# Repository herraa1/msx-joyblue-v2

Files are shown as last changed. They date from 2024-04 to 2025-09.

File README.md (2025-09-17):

# Bluetooth controller adapter for MSX (msx-joyblue) v2

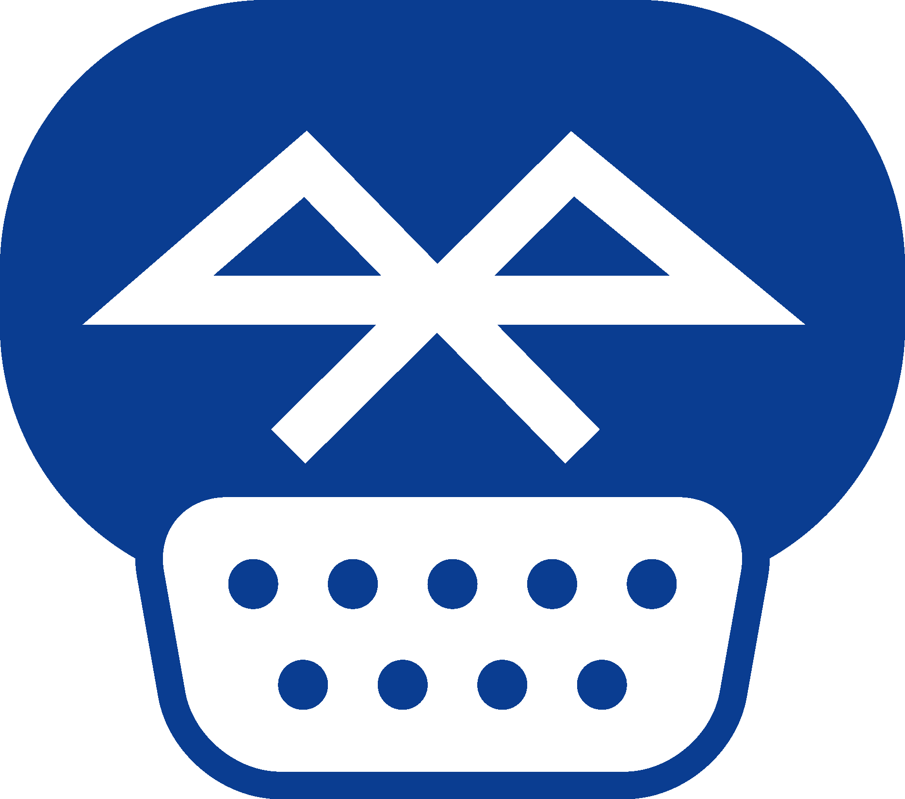
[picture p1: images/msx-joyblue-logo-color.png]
[](images/msx-joyblue-logo-color.png)

Connect Bluetooth controllers to [MSX computers](https://www.msx.org/wiki/)

## Introduction

The msx-joyblue is an adapter that allows connecting Bluetooth controllers to [MSX General Purpose I/O Interfaces](https://www.msx.org/wiki/General_Purpose_port) (aka joystick ports).

The adapter is based on the [unijoysticle2](https://github.com/ricardoquesada/unijoysticle2) and [bluepad32](https://github.com/ricardoquesada/bluepad32) projects, both owned by Ricardo Quesada.

The main features of the msx-joyblue v2 adapter are:
* small size
* made of widely available electronic components
* uses SMD components, so good soldering skills are needed to build the adapter
* emulates up to two MSX joysticks
* attaches to MSX computers using female standard DE9 connectors
* formally requires an external USB power supply as the adapter draws slightly more current than two MSX general purpose I/O interfaces can officially provide
* optionally, can be powered using MSX general purpose I/O interfaces without an external power supply if your MSX can safely supply enough current
* builtin leds provide information about the operation of the adapter

## [Hardware](hardware/kicad/)

The msx-joyblue v2 adapter uses an [ESP32-WROOM-32E chip](https://www.espressif.com/sites/default/files/documentation/esp32-wroom-32e_esp32-wroom-32ue_datasheet_en.pdf) to convert the Bluetooth controller actions to the [MSX joystick standard signalling](https://www.msx.org/wiki/Joystick_control).

A two-sided printed circuit board (PCB) is used to put together all components:
* The ESP32-WROOM-32E bluetooth MCU chip
* A CH340C USB to UART chip, to make it easy to upgrade firmware on the ESP32 chip
* A pair of S8050 NPN transistors to control the boot and enable signals of the ESP32 from the CH340C
* An AMS1117-3.3 regulator to convert the 5V from either the USB port or joystick ports to the 3.3V required by the ESP32 chip
* Four 74LS03 quad 2-input NAND gates with open collectors to completely mimic the standard MSX joystick behavior
* A pair of PTC fuses to minimize damage to the MSX computer in case something goes wrong with the board
* Several additional required components (diodes, leds, resistors, ceramic capacitors and an electrolytic capacitor)
* PH2.0 connectors are used to connect cable extensions
* A 2.0 pitch I2C header is added for future extensions
* Jumpers are provided to enable different power options
* A slider switch is used to enable powering the adapter from the MSX side
* Three momentary push buttons are used to reset the board, swap joysticks or change the operation mode

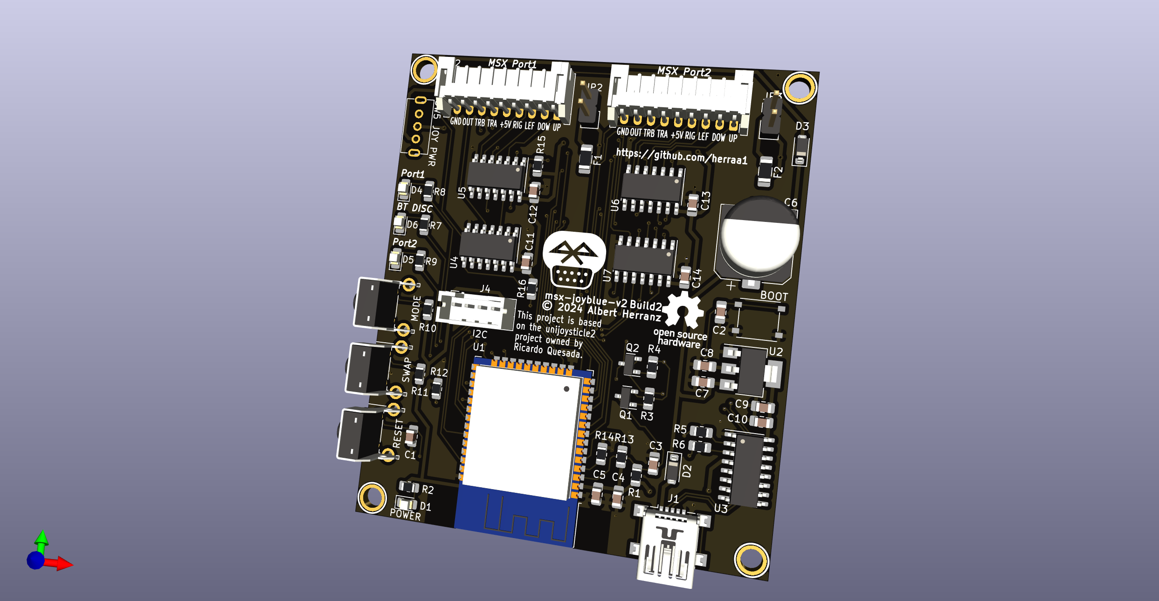
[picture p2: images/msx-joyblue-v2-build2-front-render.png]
[](images/msx-joyblue-v2-build2-front-render.png)

Connection to the MSX general purpose I/O interfaces is implemented using DE9 joystick extension cables with a female DE9 connector on one side and a loose end on the other side.
The MSX joystick extension cable loose end is wired according to the following pinout mapping.

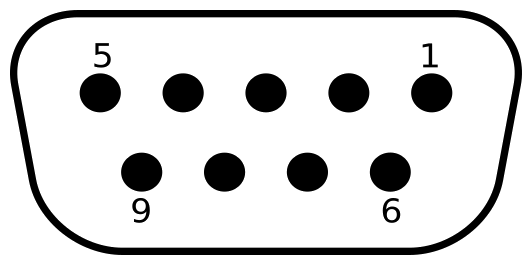
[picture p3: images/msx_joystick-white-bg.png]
| [](images/msx_joystick-white-bg.png) |
|:--|
| MSX joystick connector pinout, from controller plug side |

| MSX side pin | Cable color (may vary) | Signal |
| --- | --- | --- |
| 5 | Brown | +5v |
| 4 | Orange | RIGHT  |
| 3 | Grey | LEFT |
| 2 | Black | DOWN |
| 1 | Red | UP |
| 6 | Green | TRIG1  |
| 7 | White | TRIG2  |
| 8 | Blue | STROBE |
| 9 | Yellow | GND |

> [!WARNING]
> The msx-joyblue v2 adapter uses a different pin order on the PH2.0 header than the msx-joyblue v1 adapter.
>
> Make sure you respect the correct pin order for msx-joyblue-v2.
>

### Recommended Build

Please, use [msx-joyblue-v2 Build2c](#build2c) for making new boards.

You can find ready to order PCBs and the complete BoM at the [PCBWay community site](https://www.pcbway.com/project/shareproject/msx_joyblue_v2_build2c_caa88943.html).

<a href="https://www.pcbway.com/project/shareproject/msx_joyblue_v2_build2c_caa88943.html">PCB from PCBWay</a>

### [Build2c](hardware/kicad/msx-joyblue-v2-build2c)

[Interactive Bill Of Materials (BoM)](https://html-preview.github.io/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)

The Build2c adapter implements the following changes since Build2b:
* move capacitor C3 and resistor R1 closer to the ESP32 EN pin
* change C3 from 10uF to 22uF to give extra ramp up time to the 3V3 power rail

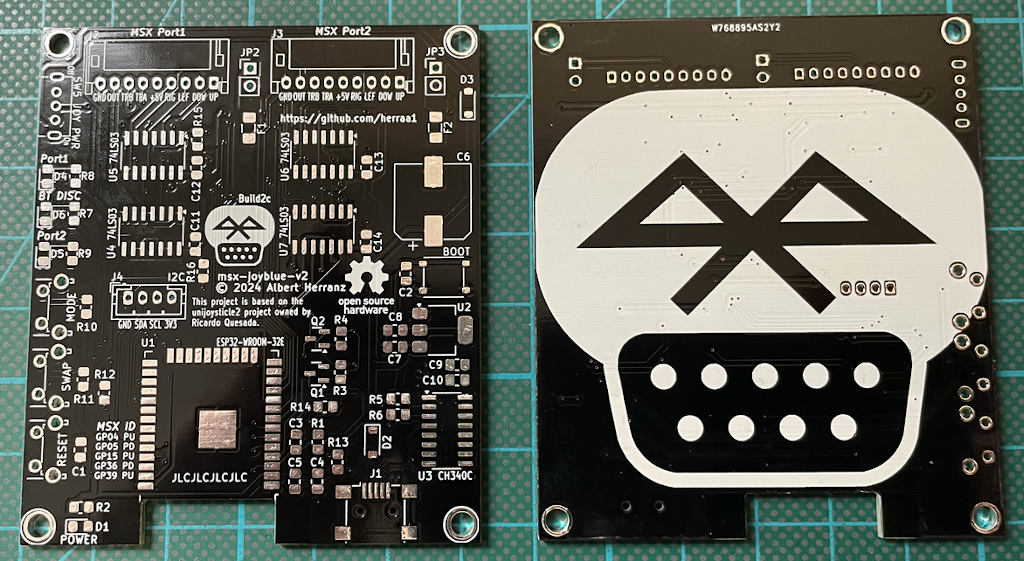
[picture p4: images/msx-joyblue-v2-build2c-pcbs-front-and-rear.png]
[](images/msx-joyblue-v2-build2c-pcbs-front-and-rear.png)|
|:--|
|msx-joyblue-v2 Build2c PCBs front and rear|

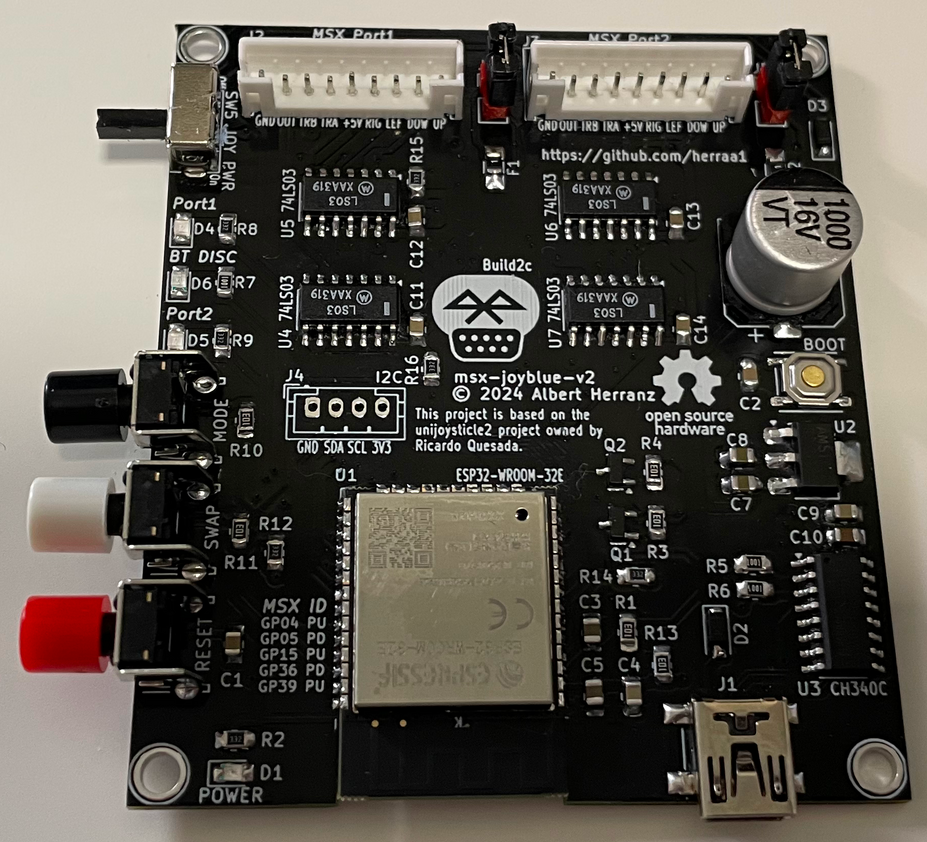
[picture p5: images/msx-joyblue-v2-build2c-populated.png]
|[](images/msx-joyblue-v2-build2c-populated.png)|
|:--|
|msx-joyblue-v2 Build2c populated PCB|

### Build2b

> [!NOTE]
> Build2b was never fabricated and has been marked obsolete. Use the [recommended build](#recommended-build) instead.

The Build2b is similar to Build2 but changes slightly some silkscreen text and graphics.

### Build2

> [!NOTE]
> Build2 has been marked obsolete. Use the [recommended build](#recommended-build) instead.

The Build2 adapter mimics completely the standard MSX joystick behavior:

* When pin8 is HIGH, the adapter puts all stick and triggers signals in high impedance mode irrespective of their status (as if stick and triggers were not hold in the standard MSX joystick schematic), which become HIGH on the MSX side via the MSX PSG related circuitry pull-ups (matching the expected behavior)
* When pin8 is LOW
  * if a stick direction or trigger is hold, the corresponding signal is pulled down to GND causing it to be LOW (matching the expected behavior)
  * if a stick direction or trigger is not hold, the corresponding signal is put in high impedance mode, which becomes HIGH on the MSX side via the MSX PSG related circuitry pull-ups (matching the expected behavior)

This build uses discrete logic components to honor the pin8 signaling (four [74LS03DR quad 2-input positive-nand gates with open collector outputs](https://www.ti.com/lit/ds/symlink/sn74ls03.pdf)) and uses open collector outputs which makes the adapter safer [^3] than the standard MSX joystick schematic depicted in the MSX Technical Data Book, as it avoids a series of undesired conditions that can lead to bus contention/short circuits.

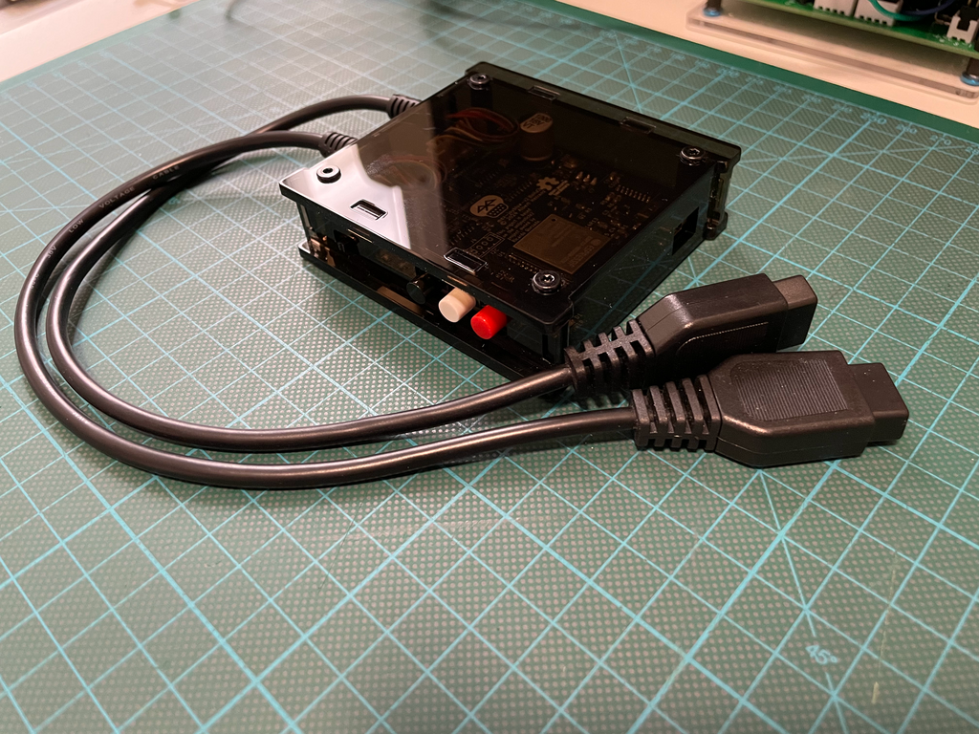
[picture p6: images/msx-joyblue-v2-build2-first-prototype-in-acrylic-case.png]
|[](images/msx-joyblue-v2-build2-first-prototype-without-enclosure.png)|[](images/msx-joyblue-v2-build2-first-prototype-in-acrylic-case.png)|
|-|-|
|msx-joyblue-v2 Build2 first prototype|msx-joyblue-v2 Build2 first prototype within acrylic case|

## [Firmware](https://github.com/ricardoquesada/bluepad32/tree/main)

The msx-joyblue v2 adapter firmware uses Ricardo Quesada [bluepad32](https://github.com/ricardoquesada/bluepad32/tree/main) library to drive Bluetooth controllers.
A [small modification](https://github.com/ricardoquesada/bluepad32/commit/9736bd169bc13ec625d469b8305d2ed2f46d6e69) to the library that enables support for MSX computers has been already commited to the _main_ branch.

See [bluepad32 documentation](https://github.com/ricardoquesada/bluepad32/tree/main/docs) for [supported Bluetooth controllers](https://github.com/ricardoquesada/bluepad32/blob/main/docs/supported_gamepads.md).

## [Enclosure](enclosure/)

A simple yet functional acrylic enclosure design is included.

## Powering the msx-joyblue adapter

The msx-joyblue adapter uses about ~107mA when operating, while a single MSX general purpose I/O interface is capable of delivering up to 50mA according to the MSX standard [^1].
That means that even using two MSX general purpose I/O interfaces (50mA + 50mA = 100mA) we are slightly over (107mA) the max current specification for the MSX general purpose I/O interfaces.

Thus, the safest way to power the msx-joyblue adapter is by powering it via the USB mini connector of the board using an external 5V USB power supply. The board automatically powers up when using the USB mini connector without enabling any switch.

Nevertheless, even if the MSX especification puts such a low limit on the current that can be drawn from a general purpose I/O interface, real MSX hardware usually can safely deliver enough current for the msx-joyblue adapter to work correctly without harming our beloved classic computers.

Taking that into account, the msx-joyblue adapter has been enabled to be optionally powered by the MSX general purpose I/O interfaces port 1 and port 2.

To enable powering the msx-joyblue adapter from _Port 1_ and/or _Port 2_, the switch SW5 _JOY PWR_ must be first turned on by sliding the switch handle to the right.

> [!NOTE]
> A [1N5819 SMD Schottky diode](https://www.diodes.com/assets/Datasheets/1N5819HW.pdf) D3 is used to avoid leaking current from the msx-joyblue adapter to the MSX in case the msx-joyblue adapter is powered by USB while the _JOY PWR_ switch is ON.
> Another [1N5819 SMD Schottky diode](https://www.diodes.com/assets/Datasheets/1N5819HW.pdf) D2 prevents backpowering the USB side from the MSX side.
> And two Positive Temperature Coeficient (PTC) resettable fuses F1 and F2 of 50mA each protect the MSX general purpose I/O interfaces port 1 and port 2 from excess of current in case something goes horribly wrong on the msx-joyblue adapter side.

To power the msx-joyblue adapter using the MSX general purpose I/O interfaces we must first understand how the PTC protections on the msx-joyblue adapter are implemented.

The selected PTCs are rated for 50mA which is the so called Hold Current (the maximum current that can flow in normal operation). There is also the Trip Current (the minimum current necessary for the PTC to move to high-resistance state) which for the selected PTCs is around 100mA. Those thresholds are dependent on temperature and voltage. And to make things more undeterministic, the behavior of the PTC when current is between those thresholds is undefined (it may trip or not).

In normal operation and for a room temperature of around 25 degrees Celsius, the selected PTCs in practice never trip below 75mA.

> [!NOTE]
> Depending on the exact PTCs installed, the trip current may be slightly different and the adapter may trip at a different point. Unless you buy the PTCs from a reliable source, it is very difficult to know the exact PTC specifications. 
>
> Remember that the PTCs are provided as a safeguard in case something goes really wrong on the adapter, not to act as an exact current limiter to strictly comply with the 50mA per-port MSX specification.

So **if our MSX computer can safely provide more than 50mA on each MSX general purpose I/O interface** (which is usually the case), we can connect both _Port 1_ and _Port 2_ to the MSX computer and turn on the SW5 _JOY PWR_ switch to power the msx-joyblue adapter. Note that we need to connect both ports even if we use just one Bluetooth gamepad, just to meet the power requirements.

Two jumpers JP2 and JP3 can be used to bypass the PTC protections for _Port 1_ and _Port 2_ respectively.

> [!WARNING]
> Bypassing the PTC protections may damage your MSX computer.
> Do not bypass the PTC protections unless you known what you are doing.

By closing JP2 (and/or JP3) and **if our MSX computer can safely provide more than 100mA on a single MSX general purpose I/O interface**, we can connect _Port 1_ (or _Port 2_) to the MSX computer and turn on the SW5 _JOY PWR_ switch to power the msx-joyblue adapter using a single joystick port.

In summary, we can use the following options to power the msx-joyblue adapter (from safest to less safe):
* via the board USB mini conector
  * leave open jumpers JP2 and JP3
  * turn off the SW5 _JOY PWR_ switch
  * connect a 5V USB power supply to the board USB mini connector
* via two MSX general purpose I/O interfaces, if your MSX can safely provide slightly more than 50mA on each MSX general purpose I/O interface
  * leave open jumpers JP2 and JP3
  * turn on the SW5 _JOY PWR_ switch
  * connect both _Port 1_ and _Port 2_ to the MSX general purpose I/O interfaces
* via one MSX general purpose I/O interface, if your MSX can safely provide more than 100mA on each MSX general purpose I/O interface
  * close jumpers JP2 and/or JP3
  * turn on the SW5 _JOY PWR_ switch
  * connect _Port 1_ or _Port 2_ to a MSX general purpose I/O interface

## Switches and Buttons

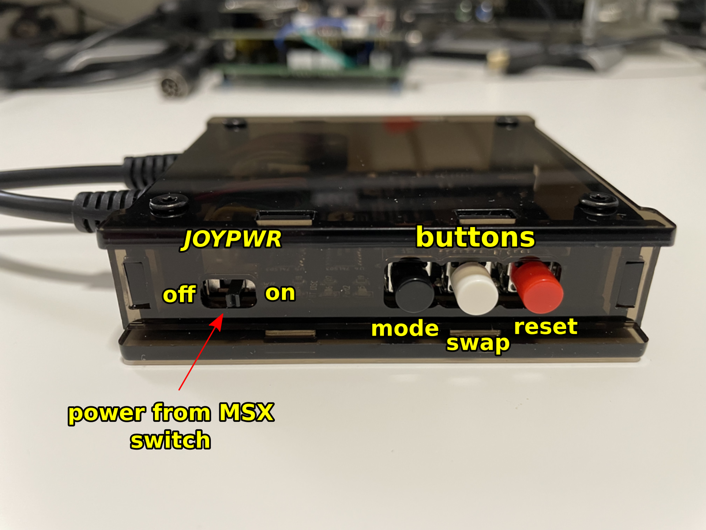
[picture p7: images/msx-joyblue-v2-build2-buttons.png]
[](images/msx-joyblue-v2-build2-buttons.png)

| **Switch** | **State** | **Description** |
|---|---|---|
| _JOYPWR_ | Off | power from MSX computer via joystick port(s) is off (except logic gates) |
| _JOYPWR_ | On | board electronics get power from MSX computer via joystick port(s) |

> [!NOTE]
> If you plug a +5V USB power supply to the USB mini connector, the adapter will turn on unconditionally irrespective of the _JOYPWR_ switch position.
>

| **Button** | **Description** |
|---|---|
| MODE | change the [operation mode](https://github.com/ricardoquesada/unijoysticle2/blob/main/docs/user_guide.md#unijoysticle-buttons-and-leds) of the connected gamepad between "basic mode" and "twin stick mode" |
| SWAP | swap connected gamepads between MSX joystick ports |
| RESET | restart the firmware, gamepads get disconnected |

## LED indicators

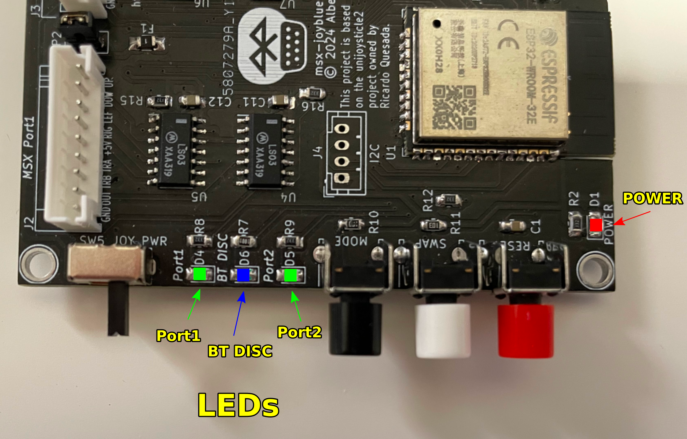
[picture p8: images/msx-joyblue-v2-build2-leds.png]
[](images/msx-joyblue-v2-build2-leds.png)

| **LED** | **State** | **Indication** |
|---|---|---|
| _POWER_ | Off | board is not receiving 3V3 power |
| _POWER_ | Solid Red | board is receiving 3V3 power |
| _Port1_ | Off | no gamepad is controlling _Port 1_ |
| _Port1_ | Solid Green | a connected gamepad is controlling _Port 1_ |
| _Port1_ | Blinking Green | Every 1sec, PTCs are tripping, see [Troubleshooting](#troubleshooting) |
| _Port2_ | Off | no gamepad is controlling _Port 2_ |
| _Port2_ | Solid Green | a connected gamepad is controlling _Port 2_ |
| _BT DISC_ | Off | Bluetooth discovery is off, no new connections are accepted, existing connections (if any) stay on |
| _BT DISC_ | Solid Blue | Bluetooth discovery is on, new connections are accepted, both "connects" and "re-connects" are accepted |

See also the [Unijoysticle user guide](https://github.com/ricardoquesada/unijoysticle2/blob/main/docs/user_guide.md#unijoysticle-buttons-and-leds), keeping in mind that led colors are slightly different.

## Troubleshooting

**Q: Just after powering the board _POWER_ led is solid red, _Port2_ and _BT DISC_ leds are off and the _Port1_ led is solid green, but the adapter does not work**

**A:** Press the reset button to reinitialize the adapter, the _BT DISC_ led should go solid blue shortly, when the adapter is ready.

**Q: I did the reset, but now the _Port1_ led blinks every second, the _BT DISC_ led is off and the _Port2_ is solid green but the adapter does not work**

**A:** The PTC fuses are tripping preventing the adapter to properly work. See the [Powering the msx-joyblue adapter](#powering-the-msx-joyblue-adapter) section: use a USB power supply or install the fuse bypass jumpers.

**Q: The _BT DISC_ led went off, what happened?**

**A:** You either have 2 gamepads already connected or have turned on the [_Twin Stick_ mode](https://github.com/ricardoquesada/unijoysticle2/blob/main/docs/user_guide.md#twin-stick-mode-aka-enhanced-mode).

This can happen too if the PTC fuses are tripping (see previous question).

**Q: My Wiimote does not connect**

**A:** If the adapter was previously connected, try pushing any Wiimote button until the Wiimote connects. If that does not work, open the battery compartment and press the red _SYNC_ button to pair the Wiimote with the adapter.

## Compatibility Tests

| **Model** | **Adapter PCB v2 Build2c** |
|---|---|
| [Sony MSX HB-101P](https://www.msx.org/wiki/Sony_HB-101P) | OK |
| [Sony MSX HB-501F](https://www.msx.org/wiki/Sony_HB-501F) | OK |
| [Toshiba MSX HX-10P](https://www.msx.org/wiki/Toshiba_HX-10P) | OK |
| [Philips MSX2 VG-8235](https://www.msx.org/wiki/Philips_VG-8235) | OK |
| [Panasonic MSX2+ FS-A1WSX](https://www.msx.org/wiki/Panasonic_FS-A1WSX) | OK |
| [Omega MSX2+](https://github.com/skiselev/omega) | OK |
| [MSXVR](https://msxvr.com/en/) | OK |
| [Tides Rider](https://genami.shop/products/tides-rider-hdk) | OK |
| [JFF-TMSHAT](https://github.com/herraa1/JFF-TMSHAT) | OK |

## Build Instructions

Follow these [Build instructions](Build.md) in order to assemble the msx-joyblue v2 adapter.

## References

Ricardo Quesada bluepad32 library
* https://github.com/ricardoquesada/bluepad32

Ricardo Quesada Unijoysticle2 project
* https://github.com/ricardoquesada/unijoysticle2

MSX general purpose I/O interface
* https://www.msx.org/wiki/General_Purpose_port

[^1]: https://www.msx.org/wiki/General_Purpose_port
[^2]: https://www.msx.org/wiki/MSX-HID
[^3]: https://www.msx.org/wiki/Joystick/joypad_controller (see "Undesired Conditions")

## Image Sources

* https://www.oshwa.org/open-source-hardware-logo/
* https://en.wikipedia.org/wiki/File:Numbered_DE9_Diagram.svg
* https://commons.wikimedia.org/wiki/File:Bluetooth.svg

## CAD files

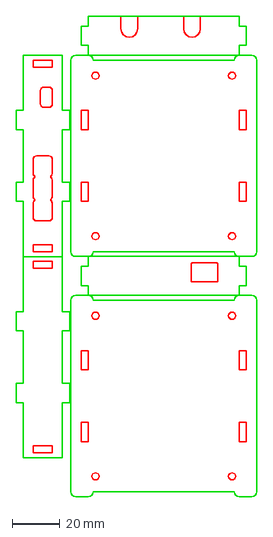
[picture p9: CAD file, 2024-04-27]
enclosure/msx-joyblue-v2-case-acrylic-3mm-ready-to-lasercut.dxf
100.4 x 200.5 mm

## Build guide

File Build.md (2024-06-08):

# Build Instructions

This document describes how to assemble the msx-joyblue v2 adapter.

# Assembling the msx-joyblue v2 adapter

## Bill Of Materials

| **ref** | **component** | **req_pcs** | **item_description** | **item_option** | **pcs_per_item** | **req_items** | **link** |
| --- | --- | --- | --- | --- | --- | --- | --- |
| C1,C2,C4,C9,C11,C12,C13,C14 | 0805 0.1uF capacitor | 8 | 100pcs 0805 SMD Chip Multilayer Ceramic Capacitor 0.5pF - 47uF 10pF 22pF 100pF 1nF 10nF 100nF 0.1uF 1uF 2.2uF 4.7uF 10uF 22uF | 100nF | 100 | 1 | [aliexpress](https://www.aliexpress.com/item/1005005690917856.html) |
| C3,C5,C7,C8 | 0805 22uF capacitor | 4 | 100pcs 0805 SMD Chip Multilayer Ceramic Capacitor 0.5pF - 47uF 10pF 22pF 100pF 1nF 10nF 100nF 0.1uF 1uF 2.2uF 4.7uF 10uF 22uF | 22UF | 100 | 1 | [aliexpress](https://www.aliexpress.com/item/1005005690917856.html) |
| C6 | 10x10.5 2200uF aluminum capacitor | 1 | 10PCS 10X10.5 chip aluminum electrolytic capacitor 10V 16V 25V 35V 50V 63V 100V 100UF 220UF 330UF 470UF 680UF 1000UF | 16V1000UF | 10 | 1 | [aliexpress](https://www.aliexpress.com/item/1005005475565293.html) |
| C10 | 0805 1uF capacitor | 1 | 100pcs 0805 SMD Chip Multilayer Ceramic Capacitor 0.5pF - 47uF 10pF 22pF 100pF 1nF 10nF 100nF 0.1uF 1uF 2.2uF 4.7uF 10uF 22uF | 1UF | 100 | 1 | [aliexpress](https://www.aliexpress.com/item/1005005690917856.html) |
| R2,R8,R9,R12,R14,R15,R16 | 0805 3.3K resistor | 7 | 200PCS 660PCS 720PCS 4000PCS 0402 0603 0805 1206 1210 2512 SMD Resistor Kit igmopnrq Assorted Kit 10K 100K 1K 1R 100R 220R 1% 5% | 0805 720PCS 36Values | 20 | 1 | [aliexpress](https://es.aliexpress.com/item/1005005671741256.html) |
| R1,R3,R4,R10,R11,R13 | 0805 10K resistor | 6 | 200PCS 660PCS 720PCS 4000PCS 0402 0603 0805 1206 1210 2512 SMD Resistor Kit igmopnrq Assorted Kit 10K 100K 1K 1R 100R 220R 1% 5% | 0805 720PCS 36Values | 20 | 0 | [aliexpress](https://es.aliexpress.com/item/1005005671741256.html) |
| R5,R6,R7 | 0805 1K resistor | 3 | 200PCS 660PCS 720PCS 4000PCS 0402 0603 0805 1206 1210 2512 SMD Resistor Kit igmopnrq Assorted Kit 10K 100K 1K 1R 100R 220R 1% 5% | 0805 720PCS 36Values | 20 | 0 | [aliexpress](https://es.aliexpress.com/item/1005005671741256.html) |
| D2,D3 | SOD-123 1N5819 schottky diode | 2 | 100pcs SMD diode 0805 SOD-123 S4 1N5819 1N5819W 1N5819WS 1N5819WT SOD-323 SOD-523 1206 0603 Schottky diodes | SOD-123 | 100 | 1 | [aliexpress](https://www.aliexpress.com/item/1005006207828437.html) |
| D1 | 0805 Red Led | 1 | 100pcs=5colors x 20pcs 5050 5730 3014 1210 2835 3528 1206 0805 0603 0402 SMD LED Diode Kit Red / Green / Blue / White / Yellow | Emitting Color: 0805 5colors 20pcs | 20 | 1 | [aliexpress](https://www.aliexpress.com/item/4001031824623.html) |
| D4,D5 | 0805 Green Led | 2 | 100pcs=5colors x 20pcs 5050 5730 3014 1210 2835 3528 1206 0805 0603 0402 SMD LED Diode Kit Red / Green / Blue / White / Yellow | Emitting Color: 0805 5colors 20pcs | 20 | 0 | [aliexpress](https://www.aliexpress.com/item/4001031824623.html) |
| D6 | 0805 Blue Led | 1 | 100pcs=5colors x 20pcs 5050 5730 3014 1210 2835 3528 1206 0805 0603 0402 SMD LED Diode Kit Red / Green / Blue / White / Yellow | Emitting Color: 0805 5colors 20pcs | 20 | 0 | [aliexpress](https://www.aliexpress.com/item/4001031824623.html) |
| U4,U5,U6,U7 | 74LS03DR | 4 | 10pcs SN74LS00DR SN74LS02DR SN74LS04DR SN74LS05DR SN74LS08DR SN74LS14DR SN74LS32DR SN74LS03DR SN74LS05DR2 SN74LS06DR SOP-14 | SN74LS03DR | 10 | 1 | [aliexpress](https://www.aliexpress.com/item/1005006266817606.html) |
| U1 | ESP32-WROOM-32E | 1 | 1pcs ESP-WROOM-32/32D/32U/32E WiFi Bluetooth 4.2 dual-core CPU MCU low- Bluetooth 240MHZ ESP32 chip ESP-32S | ESP32-WROOM-32E | 1 | 1 | [aliexpress](https://www.aliexpress.com/item/1005006387597679.html) |
| U2 | AMS1117-3.3 | 1 | 50PCS AMS1117 series AMS1117-1.2 AMS1117-1.5 AMS1117-1.8 AMS1117-2.5 AMS1117-3.3 AMS1117-5.0 SOT223 new | AMS1117-3.3V | 50 | 1 | [aliexpress](https://www.aliexpress.com/item/1005006122970723.html) |
| U3 | CH340C | 1 | 10PCS Chipset CH340C CH340 SOP-16 | | 10 | 1 | [aliexpress](https://www.aliexpress.com/item/1005006121593217.html) |
| F1,F2 | 1206 50mA PTC fuse | 2 | 10PCS Self-Recoverable SMD Fuse PPTC 0805 0.05A 50MA 100MA 0.2A 0.35A 0.5A 750MA 1A 1.1A 1.25A 1.5A 2A 6V 9V 12V 16V 24V 30V 48V | 0805 50MA 24V | 10 | 1 | [aliexpress](https://www.aliexpress.com/item/1005005816556049.html) |
| SW1,SW3,SW4 | 6x6mm momentary switch right angle | 3 | 6x6mm Panel PCB Momentary Tactile Tact Mini Switch 6\*6\*4.3/5/6/7/89/10/12mm Right Angle With stent 6x6x4.3mm 5mm 6mm 7mm 8mm 9mm  | 6x6x9mm | 20 | 1 | [aliexpress](https://www.aliexpress.com/item/32912894177.html) |
| SW2 | 5.1x5.1 1pst push button | 1 | 10PCS 3\*6 3\*4 4\*4 SMD Tactile Tact Push Button Switch 2Pin 4Pin Touch Micro Switch 3x4x2 3x6x4.3 3x6x2.5 3x6x5 4x4x1.5 4\*4\*2.5 | 4X4X1.5MM | 10 | 1 | [aliexpress](https://www.aliexpress.com/item/1005004067514307.html) |
| SW5 | SK12D07G6 1P2T switch | 1 | 10PCS SK12D07G3/4/5/6/7MM Mini Vertical Slide Switch 1P2T 3 Pin Toggle Switch SMD PCB DPDT Vertical Switch High Quality | 6MM | 10 | 1 | [aliexpress](https://www.aliexpress.com/item/1005005897805728.html) |
| Q1,Q2 | SOT-23 S8050 transistor | 2 | SOT23 S9014 S9015 S8050 S8550 SS8050 SS8550 S9012 S9013 S9018 J3Y STY Y1 Y2 2T1 J3 J6 M6 J8 Transistor XC6206P332MR XC6206P182MR | 50PCS S8050 J3Y | 50 | 1 | [aliexpress](https://www.aliexpress.com/item/1005004417008064.html) |
| JP2,JP3 | 2.54mm pin header | 1 | 30PCS 40 Pin Breakable Pin Header 2.54mm Single Row Male Header Connector Kit PCB Pin Strip For Arduino | | 30 | 1 | [aliexpress](https://www.aliexpress.com/item/1005006186853439.html) |
| J1 | USB Mini B connector | 1 | 10PCS Mini USB SMD 5 Pin Female Mini B Socket Connector Plug Straight DIP Jack Connector Plug-in | Color: G | 10 | 1 | [aliexpress](https://www.aliexpress.com/item/1005004679855929.html) |
| J2,J3 | 9pin PH2.0 straight male connector | 2 | 20sets XH 2.54mm PH2.0 Straight Right angle 2/3/4/5/6/7/8/9/10/12/14/15/16/20 pin JST Connector XHP PHR 2.5 Male Female Terminal | Straight Type, PH2.0mm, 9P | 20 | 1 | [aliexpress](https://www.aliexpress.com/item/1005003475317382.html) |
| \- | PCB | 1 | msx-joyblue-v2 build2c pcb | | 5 | 1 | [PCBWay](https://www.pcbway.com/project/shareproject/msx_joyblue_v2_build2c_caa88943.html) |

## Tools

I used the following tools and materials to assemble the msx-joyblue v2 board:

* silicone heat-resistant mat (TE-616 400x290mm)
* electronic microscope with 2 LEDs (KKmoon 3" LCD 10X-300X 3.0MP 1080P HDMI electronic digital video microscope)
* soldering station (Yihua 908D)
* T1.C "horseshoe" soldering tip (900M series)
* flux (Mechanic UV80 flux paste)
* solder (0.5mm, for hobby projects you may use 60% Sn / 40% Pb Flux 2% at your own risk)
* desoldering wick (2.5mm is fine, for correcting mistakes if you are human)

## Testing the Integrated Circuits

It is highly recommended to test the integrated circuits before soldering them, specially if you buy chips from cheap Asian stores.
Otherwise, you'll need to desolder any non-working chip after soldering them on the PCB and realizing they really don't work.

### CH340C

The CH340C is a SOP-16 packaged USB to serial chip that requires few external components to function, thus it is very easy to build a test circuit.

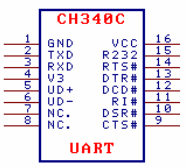
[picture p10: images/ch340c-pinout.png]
|[](images/ch340c-pinout.png)|
|:--|
|CH340C pinout|

In order to minimally test a CH340C chip we just need to connect GND, VCC, USBD+, USBD- and put a 100nF capacitor between V3 and GND, as indicated in the following diagram.

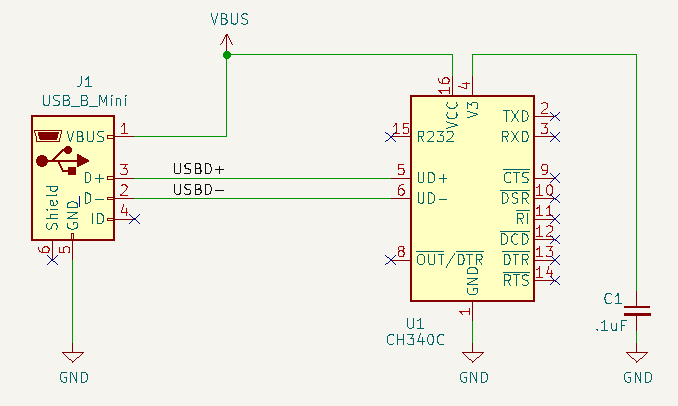
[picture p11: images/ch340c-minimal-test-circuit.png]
|[](images/ch340c-minimal-test-circuit.png)|
|:--|
|CH340C minimal test circuit|

This circuit can be easily built using the following components:
* [USB-A male to 2.54mm female dupont header cable](https://www.aliexpress.com/item/4000916333572.html)
* [SOP-16 to DIP-16 adapter](https://www.aliexpress.com/item/1005005939115495.html)
* [0.1uF ceramic capacitor](https://www.aliexpress.com/item/32973259342.html)
* [male-male jumper wires](https://www.aliexpress.com/item/1005006263457745.html)
* [breadboard](https://www.aliexpress.com/item/1005006102317693.html)

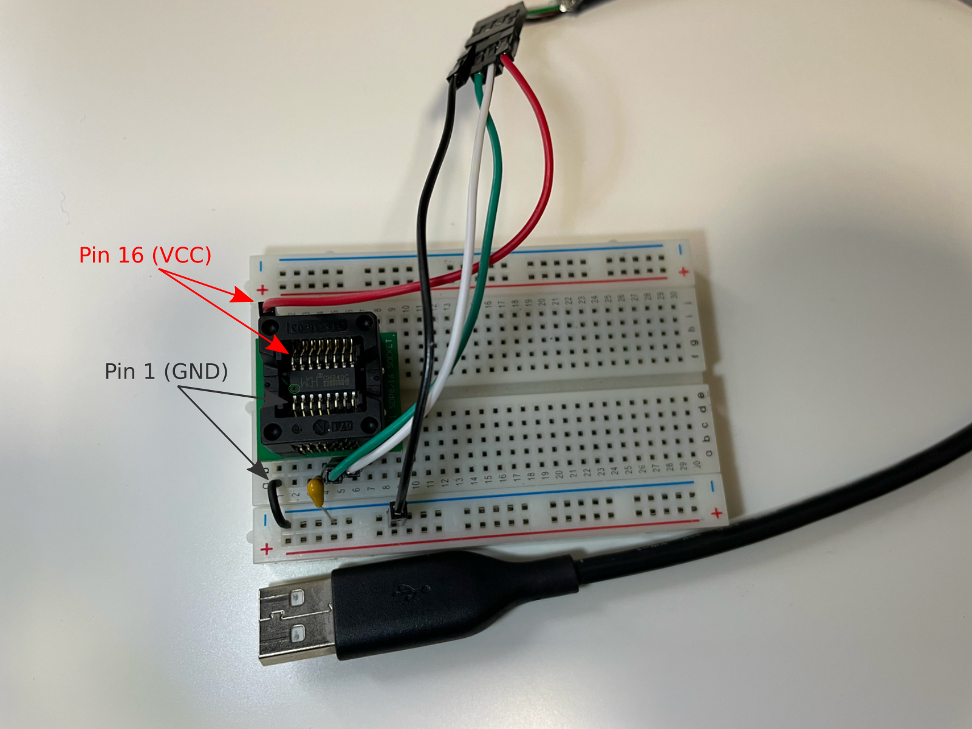
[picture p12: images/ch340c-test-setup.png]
|[](images/ch340c-test-setup.png)|
|:--|
|CH340C test setup|

When you have the test circuit ready, push down and hold the top of the SOP-16 to DIP-16 adapter to open the adapter pin "jaws", using precision tweezers insert and perfectly align the CH340C chip with the adapter pin "jaws" and finally release the top of the adapter to have the chip secured and correctly connected. You can now connect the USB-A cable to your computer and look for the CH340 device in the list of USB devices.

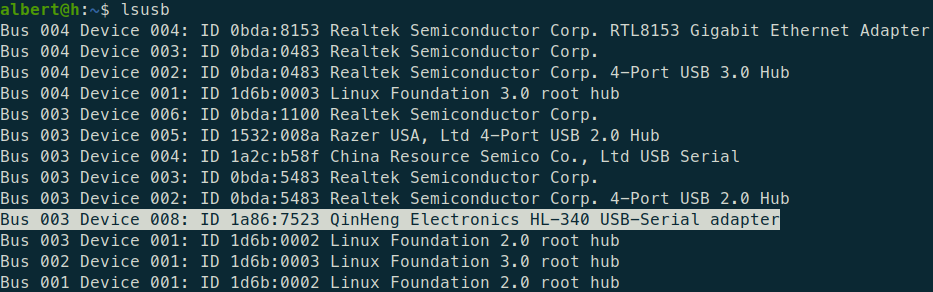
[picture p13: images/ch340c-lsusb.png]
|[](images/ch340c-lsusb.png)|
|:--|
|CH340C adapter correctly recognized|

To remove the chip from the SOP-16 to DIP-16 adapter you will need to push and hold again the top of the adapter, lift gently the chip using tweezers and then release the top of the adapter when it is empty.

### ESP32-WROOM-32E

The ESP32-WROOM-32E is a powerful Wi-Fi + Bluetooth + Bluetooth LE microcontroller unit module with an embedded PCB antenna.

Testing a ESP32-WROOM-32E can be achieved with a [small ready-to-use test jig](https://www.aliexpress.com/item/1005005850152605.html).

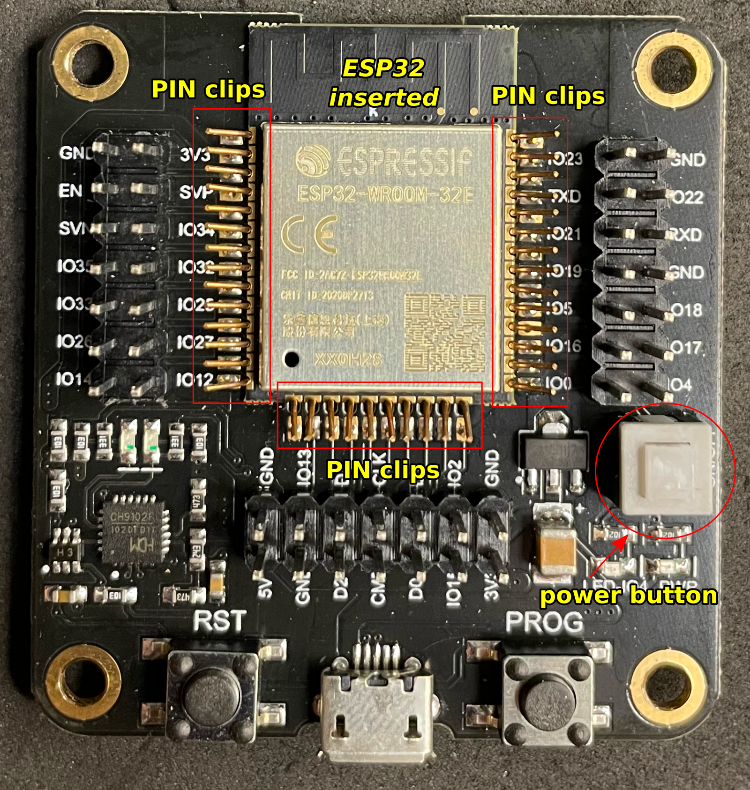
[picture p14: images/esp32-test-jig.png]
|[](images/esp32-test-jig.png)|
|:--|
|ESP32-WROOM-32E test jig|

To test a ESP32-WROOM-32E:
* Insert the ESP32-WROOM-32E into the test jig making sure that all pads are aligned with the test jig clips.

  You need to press firmly the module until it gets hold by the clips of the test jig, without breaking any clips.
* Insert a micro-USB cable into the micro-USB connector of the test jig and connect it to your PC
* Press the power button to turn on the test jig.
* Check that the USB to serial adapter shows up on the list of USB devices of your PC

<pre>
$ dmesg | tail -n 6
[  940.416575] usb 3-3.1: new full-speed USB device number <b>40</b> using xhci_hcd
[  940.517893] usb 3-3.1: New USB device found, idVendor=<b>1a86</b>, idProduct=<b>55d4</b>, bcdDevice= 4.44
[  940.517900] usb 3-3.1: New USB device strings: Mfr=0, Product=2, SerialNumber=3
[  940.517904] usb 3-3.1: Product: <b>USB Single Serial</b>
[  940.517908] usb 3-3.1: SerialNumber: XXXXXXXXXX
[  940.568222] cdc_acm 3-3.1:1.0: <b>ttyACM0: USB ACM device</b>
</pre>

<pre>
$ lsusb
Bus 004 Device 004: ID 0bda:8153 Realtek Semiconductor Corp. RTL8153 Gigabit Ethernet Adapter
Bus 004 Device 003: ID 0bda:0483 Realtek Semiconductor Corp. 4-Port USB 3.0 Hub
Bus 004 Device 002: ID 0bda:0483 Realtek Semiconductor Corp. 4-Port USB 3.0 Hub
Bus 004 Device 001: ID 1d6b:0003 Linux Foundation 3.0 root hub
Bus 003 Device 006: ID 0bda:1100 Realtek Semiconductor Corp. USB2.0 HID
Bus 003 Device 005: ID 1532:008a Razer USA, Ltd RZ01-0325, Gaming Mouse [Viper Mini]
Bus 003 Device 004: ID 1a2c:b58f China Resource Semico Co., Ltd BladeMaster TE 88K
Bus 003 Device 003: ID 0bda:5483 Realtek Semiconductor Corp. 4-Port USB 2.0 Hub
Bus 003 Device 002: ID 0bda:5483 Realtek Semiconductor Corp. 4-Port USB 2.0 Hub
<b>Bus 003 Device 040: ID 1a86:55d4 QinHeng Electronics USB Single Serial</b>
Bus 003 Device 024: ID 050d:0304 Belkin Components FSU304 USB 2.0 - 4 Ports Hub
Bus 003 Device 001: ID 1d6b:0002 Linux Foundation 2.0 root hub
Bus 002 Device 001: ID 1d6b:0003 Linux Foundation 3.0 root hub
Bus 001 Device 001: ID 1d6b:0002 Linux Foundation 2.0 root hub
</pre>

* Then finally use esptool to request information about the chip.

  If the chip works fine it will be properly detected and will appear as ESP32-D0WD-V3 or ESP32-D0WDR2-V3.

<pre>
$ <b>esptool.py chip_id</b>
esptool.py v3.3.4-dev
Found 1 serial ports
Serial port /dev/ttyACM0
Connecting....
Detecting chip type... Unsupported detection protocol, switching and trying again...
Connecting.......
Detecting chip type... ESP32
<b>Chip is ESP32-D0WD-V3 (revision v3.1)</b>
Features: WiFi, BT, Dual Core, 240MHz, VRef calibration in efuse, Coding Scheme None
Crystal is 40MHz
MAC: 01:23:45:67:89:ab
Uploading stub...
Running stub...
Stub running...
Warning: ESP32 has no Chip ID. Reading MAC instead.
MAC: 01:23:45:67:89:ab
Hard resetting via RTS pin...
</pre>

### SN74LS03DR

The SN74LS03DR are quad 2-input NAND gates with open collector outputs.

If you own a TL866II+ programmer you can easily verify that the 74LS03 chips are working correctly.

Use the same SOP-16 to DIP-16 adapter that you used to test the CH340C, but keep in mind that the SN74LS03DR only has 14 pins so you need to properly align the IC leaving 2 pairs of pins unconnected.

Insert the DIP-16 adapter into the TL866II+ connector making sure that pin 1 is aligned correctly (use the engraved orientation diagram as a reference).

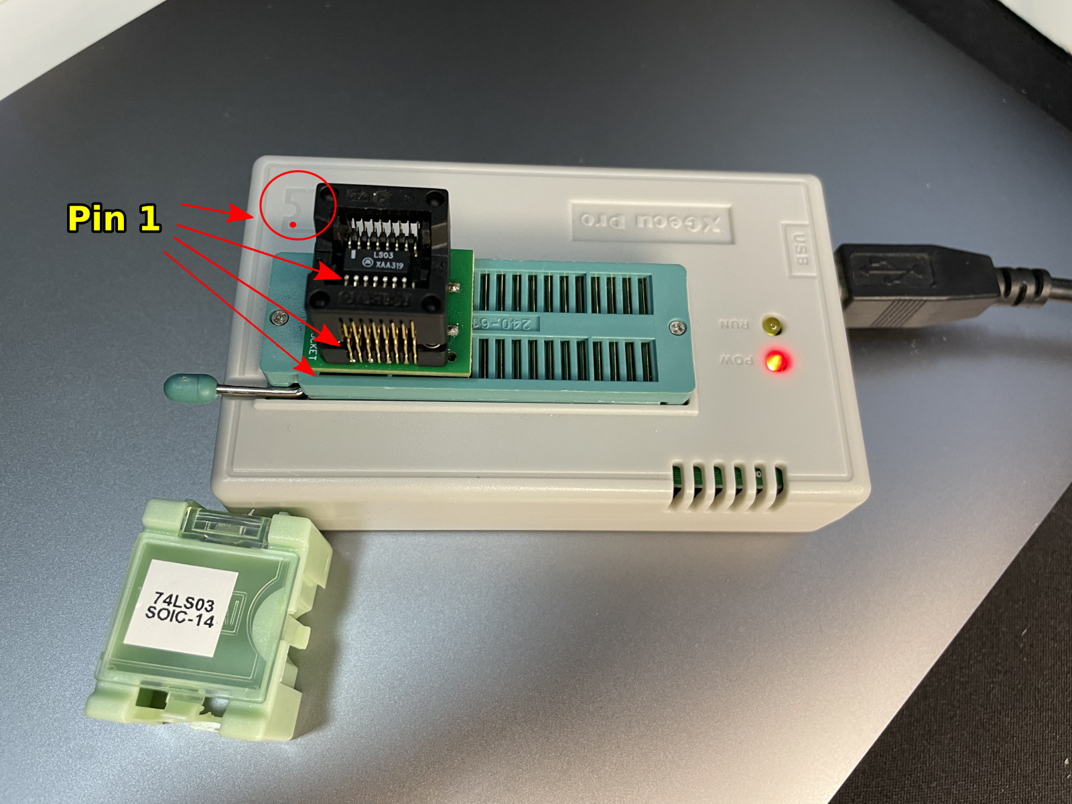
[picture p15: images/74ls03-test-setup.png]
|[](images/74ls03-test-setup.png)|
|:--|
|SN74LS03DR test setup|

Then use the minipro software to test the logic gates.

<pre>
$ <b>./minipro -p 7403 -T</b>
Found TL866II+ 04.2.132 (0x284)
      1  2  3  4  5  6  7  8  9  10 11 12 13 14
0000: 0  0  Z  0  0  Z  G  Z  0  0  Z  0  0  V
0001: 1  0  Z  1  0  Z  G  Z  1  0  Z  1  0  V
0002: 0  1  Z  0  1  Z  G  Z  0  1  Z  0  1  V
0003: 1  1  L  1  1  L  G  L  1  1  L  1  1  V
<b>Logic test successful.</b>
</pre>

## Board assembly instructions

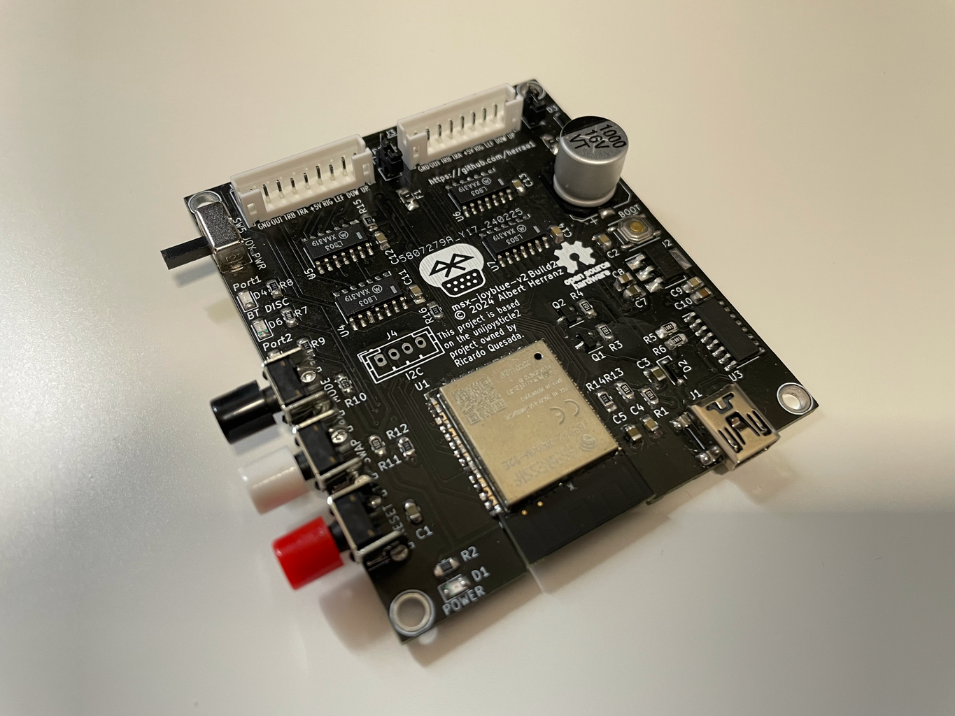
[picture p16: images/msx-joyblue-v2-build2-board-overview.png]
[](images/msx-joyblue-v2-build2-board-overview.png)

### Component orientation

#### Polarized components

As always, make sure to align all the polarized components correctly:
* the aluminum capacitor has a black color zone at the top indicating the negative pad, and also the base is beveled on the positive pad which must match the footprint at the PCB
* the leds have color markings near the negative pad
* the 1N5819 schottky diodes have a strip on the negative pad
* the CH340C USB to serial chip has a dot marking near pin 1

  Pin 1 of CH340C must be aligned to the PCB footprint (depending on the footprint used) with the pin marked with a small arrow or the pin where the silkscreen line extends to the end of the pin
* the SN74LS03DR chips have a vertical line close to the side where pin 1 is, but it does NOT indicate which pin is pin 1 (pin1 is on the bottom left when you orient the chip so that the markings can be read correctly)

  Pin1 of SN74LS03DR must be aligned to the PCB footprint in the same way as described for the CH340C chip.

* PH2.0 headers must be oriented according to the PCB footprint silkscreen drawing

* The rest of polarized components (3V3 regulator, transistors, momentary mini buttons, tactile push button, sliding switch and USB mini connector) can only be installed in the correct orientation

|[](images/msx-joyblue-v2-build2-polarized-components-orientation.png)|
|:--|
|Polarized components orientation|

#### Non-polarized components

All ceramic capacitors, resistors, fuses and pin headers are non-polarized and can be installed in any orientation.

### Soldering

You can use many different strategies and techniques to solder the components into the PCB.

You can have a look at one of the many tutorials available on youtube:

(https://www.youtube.com/watch?v=EW9Y8rDm4kE)
(https://www.youtube.com/watch?v=zS0w5-6keVU)
(https://www.youtube.com/watch?v=4SzV2_ZmRK0)

I use this technique for SMD components:
* Put flux paste/gel into the PCB pads of the footprint of the component that you want to solder.
* Place and align the component on top of its PCB footprint. The component will stick to the PCB thanks to the flux paste/gel.

  It is advisable to use precision tweezers and a microscope to make the component alignment, unless you have very good eyesight.

* Put a really small quantity of solder into the base of the T1.C tip of the soldering iron, which should be already at 350 degrees Celsius. The flux of the solder will evaporate while at the tip, but that's no problem as we will use the flux from the PCB pads.
* Hold the component with tweezers so that it does not move while soldering the first of its pads.
* Put the tip of the soldering iron with the solder so that it touches both the PCB pad and component leg. The solder at the soldering iron tip will mix with the flux at the PCB pad creating a good solder joint.

  You can move the soldering iron tip into and out of the component leg to make sure the solder makes a good metal junction.

* Repeat the process with the remaining pads. If the component has many pads, solder first two pads in opposite diagonals to secure the component, then go after the rest of the pads.
* Clean the excess of flux using pure isopropyl alcohol.

I would suggest to solder the components in decreasing difficulty order, making batches of identical valued components to avoid mistakes, also leaving for the end the taller SMD components (like the aluminum capacitor and the USB mini connector) and the through-hole components (like the PH2.0 headers, right-angled buttons and sliding switch), but do as you feel comfortable.

>[!NOTE]
> You are not required to solder the ESP32 ground pad at the bottom of the chip (this is specially relevant if you use a soldering iron to solder it).

>[!NOTE]
> After soldering it is strongly advisable to verify the continuity of all signals using a digital multimeter, with special emphasis on the ESP32 chip pins (which may not provide good contact with the pads, despite looking properly soldered).

[](images/msx-joyblue-v2-build2-pcb-assembly.gif)

# Preparing the joystick cables

## Bill Of Materials

| **ref** | **component** | **req_pcs** | **item_description** | **item_option** | **pcs_per_item** | **req_items** | **link** |
| --- | --- | --- | --- | --- | --- | --- | --- |
| \- | 9pin PH2.0 straight female socket | 2  | 10PCS JST Plugs Sockets XH2.54/PH2.0/SH1.0/ZH1.5/JST1.25 Connectors 10/9/8/7/6/5/4/3/2 Pin connector Case Without Wire Connector | Color: Housing Case, Package: PH 2.0mm, Pins: 9P | 10  | 1 | [aliexpress](https://www.aliexpress.com/item/1005006058022917.html) |
| \- | PH2.0 pin terminals | 18 | 500Pcs JST PH 2.0 2.0mm Metal Pins Terminal Wire Cable for Housing PH2.0 Female Socket Connector | | 500 | 1 | [aliexpress](https://www.aliexpress.com/item/1005006603250204.html) |
| \- | Cable gland 5mm | 2  | 10pcs Cable Gland Connector Rubber Strain Relief Cord Boot Protector Wire Cable Sleeve Power Tool Cellphone Charger | 5mm-black, China | 10  | 1 | [aliexpress](https://www.aliexpress.com/item/1005005914224947.html) |
| \- | Extension cable MSX | 2  | 1PC 9 Pin 1.5M Extension Cable For Sega Genesis 2 for MD2 Controller Gamepad | Color: as pic | 1 | 2 | [aliexpress](https://www.aliexpress.com/item/1005005677059954.html) |

## Tools

I used the following tools to prepare the DE9 cables:

* wire stripper & cutter (Stanley FatMax)
* PH2.0 crimping tool (SN-01BM)

## Cable assembly instructions

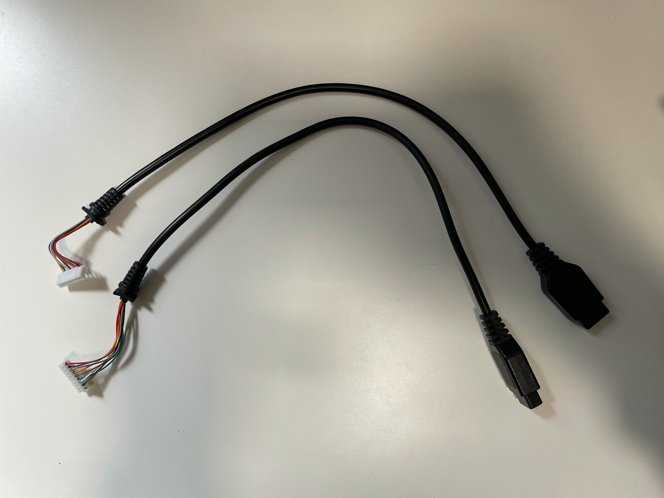
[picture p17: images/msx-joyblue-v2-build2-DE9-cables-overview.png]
[](images/msx-joyblue-v2-build2-DE9-cables-overview.png)

Although you can use the DE9 extension cables as is, they are quite long (1.5m) for the msx-joyblue adapter: it is recommended to adjust them to about 35cm long, which requires cutting the cable, stripping again the 9 internal wires and placing a new cable gland for strain relief.

You need to crimp PH2.0 metal pins to all of the joystick cable wires. Make sure that you crimp the sleeve of the wire with the rear wings of the PH2.0 metal pin only, and that the center wings crimp the stripped copper wire. If the wire is too thin to get properly crimped, you can fold a bit the stripped copper wire at the end of the wire so that the central wings have more copper volume to crimp.

Once the PH2.0 metal pins are correctly crimped you can insert them into the PH2.0 plastic housing in the specific required order.

This is the detailed procedure to prepare each of the two DE9 cable extensions:

1. Cut the DE9 extension cable leaving about 35cm from the DE9 connector.

   TBC

2. Use the wire stripper to remove about 5cm of the cable insulation at the cut end, exposing the 9 internal wires.

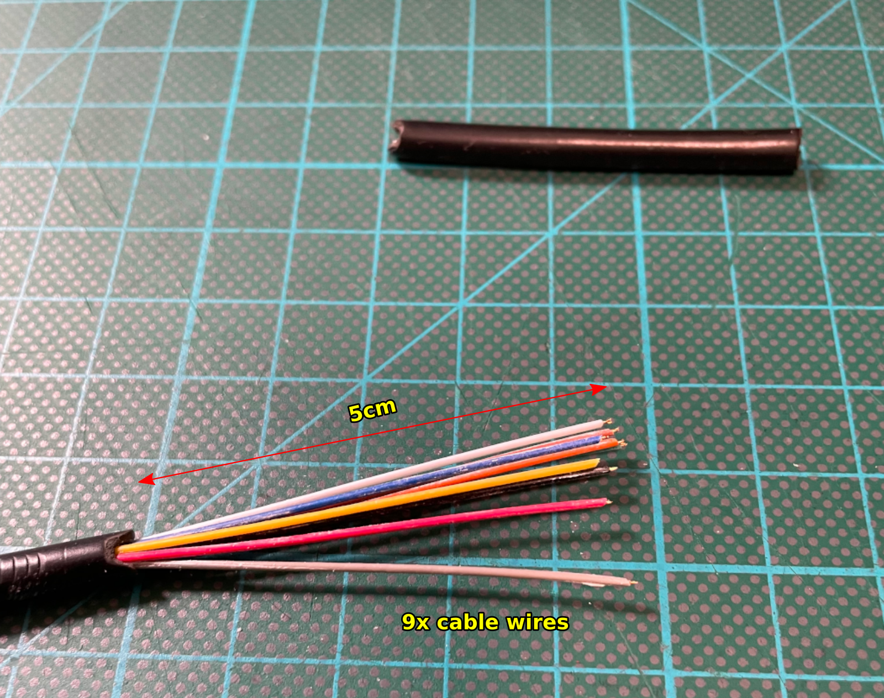
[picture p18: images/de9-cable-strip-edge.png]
[](de9-cable-strip-edge.png)

3. Insert the cable gland at the cut end of the extension cable.

   You must first insert the cable gland via its "conic" side into the 9 internal wires. From there you need to keep sliding the cable gland into the cable until the cable gland is fully inserted into the external cable insulation.
   
   You may need to use a bit of dish soap to fit the cable gland into the cable, as it fits very tight.

   TBC

4. For each one of the 9 internal wires:

   4.1. Use the wire stripper to remove about 2-3mm of the individual cable insulation

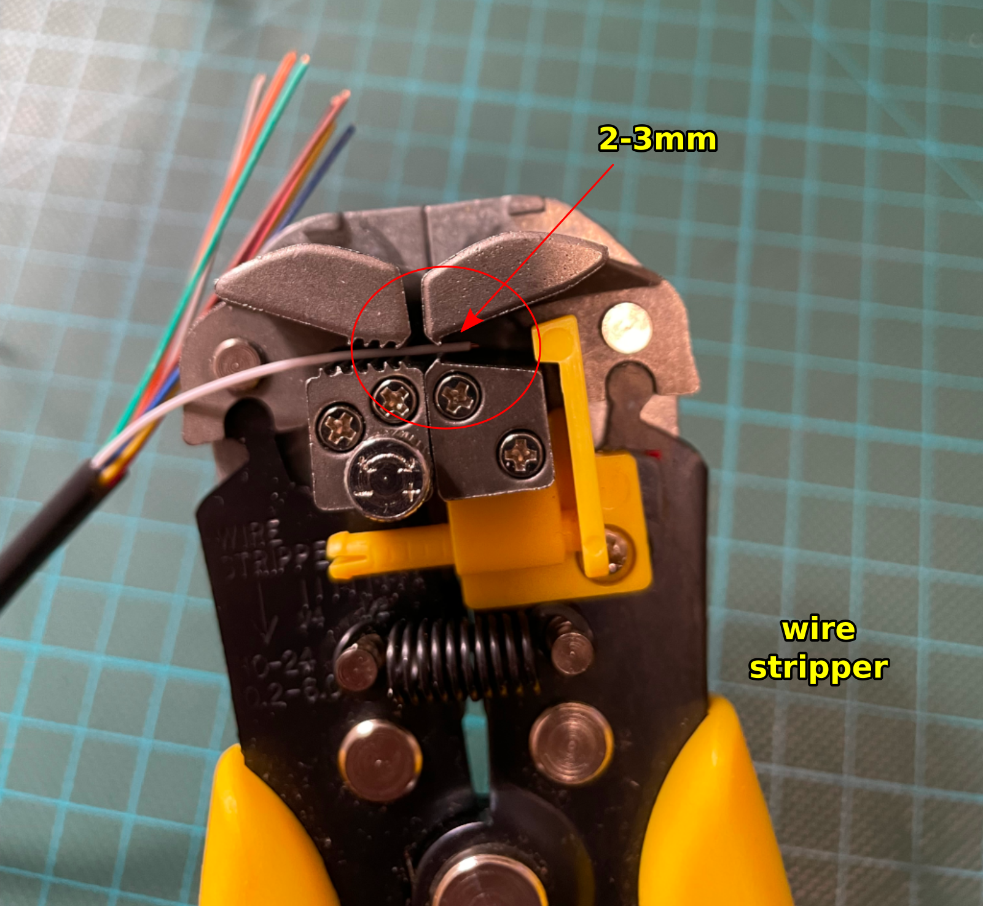
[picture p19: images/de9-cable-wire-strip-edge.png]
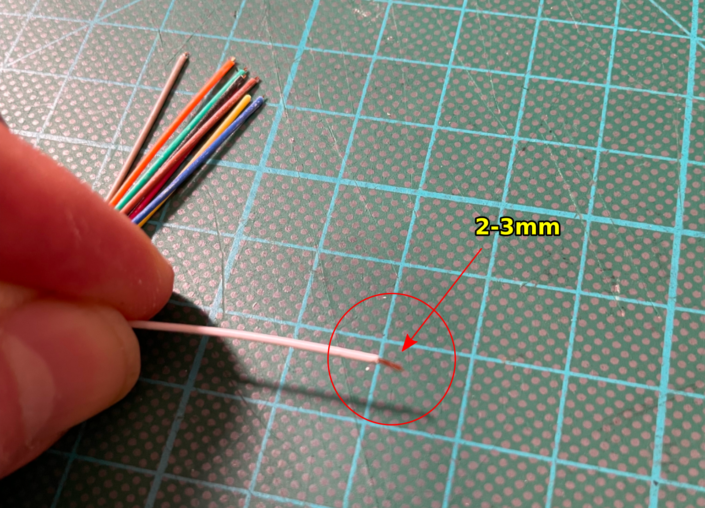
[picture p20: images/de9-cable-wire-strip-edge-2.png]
[](images/de9-cable-wire-strip-edge.png) [](images/de9-cable-wire-strip-edge-2.png)

   4.2. Fold the exposed copper wire over itself at half the distance, leaving just 1-1.5mm of exposed copper cable length at the end (this is to make enough copper available to the central pin wings of the PH2.0 metal pins).

[](images/de9-cable-wire-fold-copper.png)

   4.3. Crimp a PH2.0 metal pin to the end of the individual cable, making sure the metal pin's center wings crimp the copper and the rear wings crimp the cable insulation.

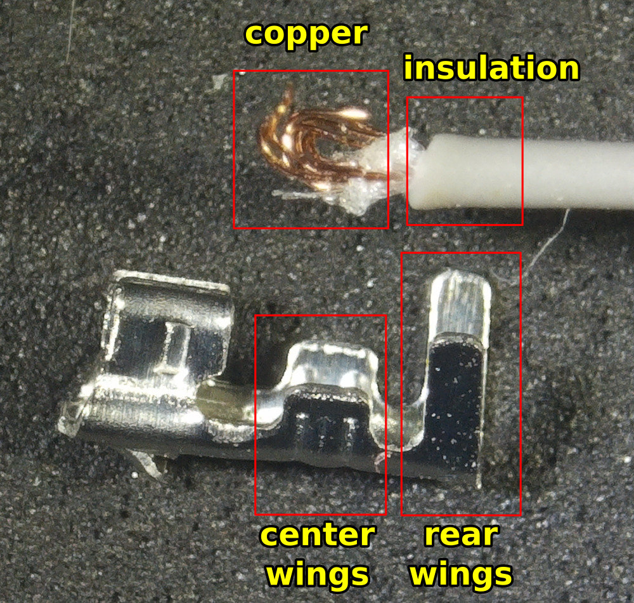
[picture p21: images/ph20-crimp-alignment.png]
[](images/ph20-crimp-alignment.png)

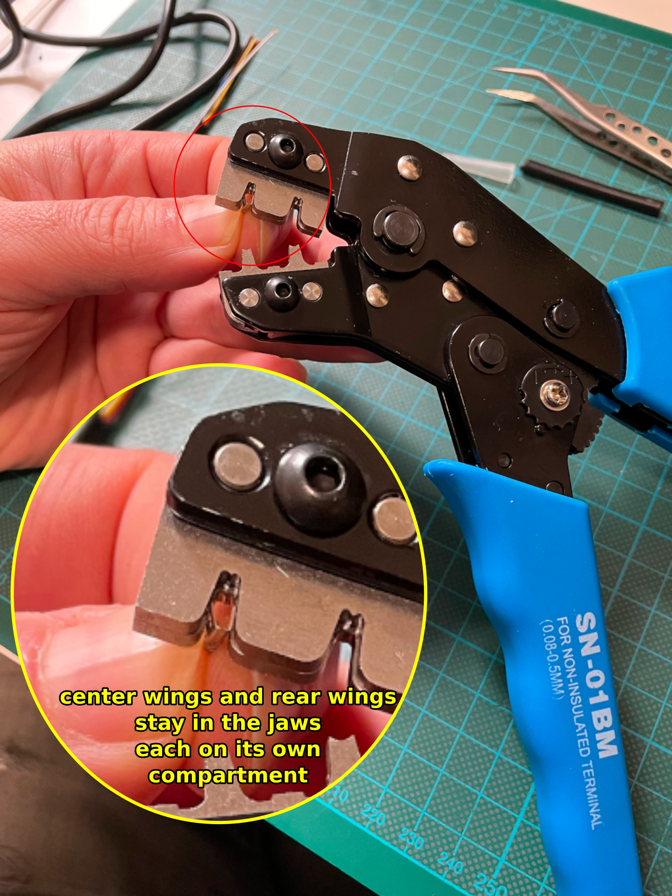
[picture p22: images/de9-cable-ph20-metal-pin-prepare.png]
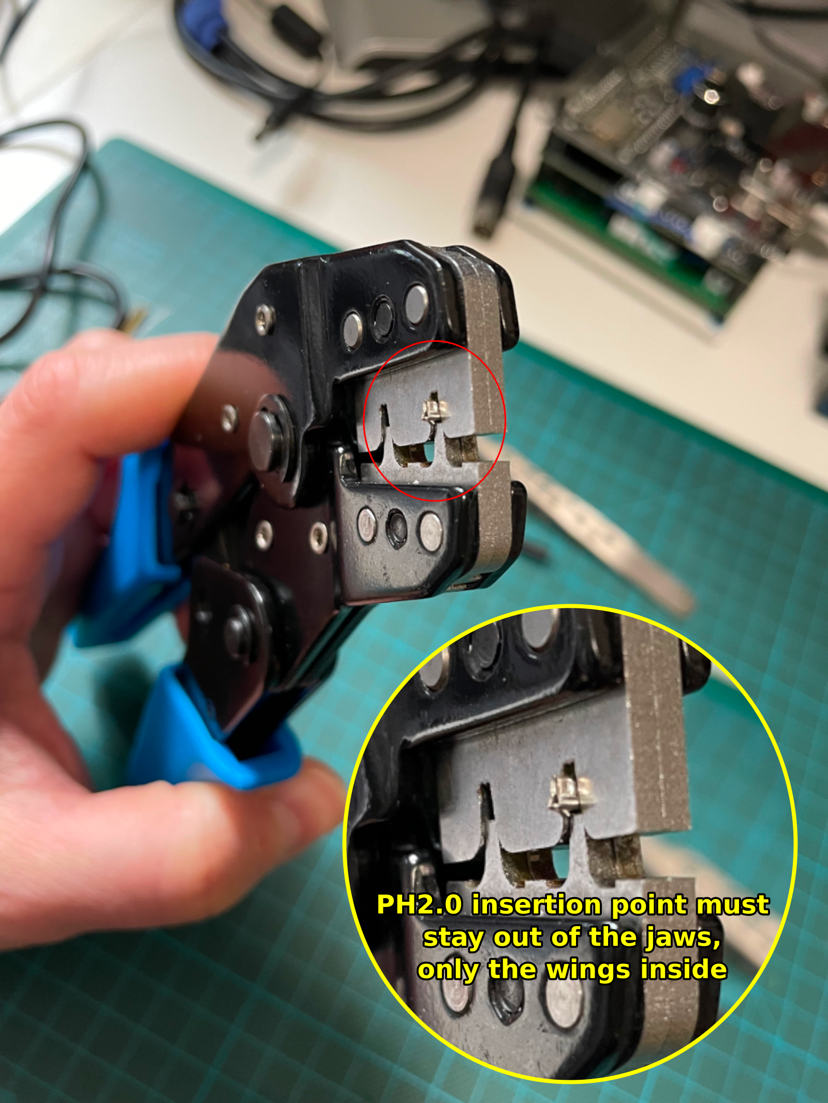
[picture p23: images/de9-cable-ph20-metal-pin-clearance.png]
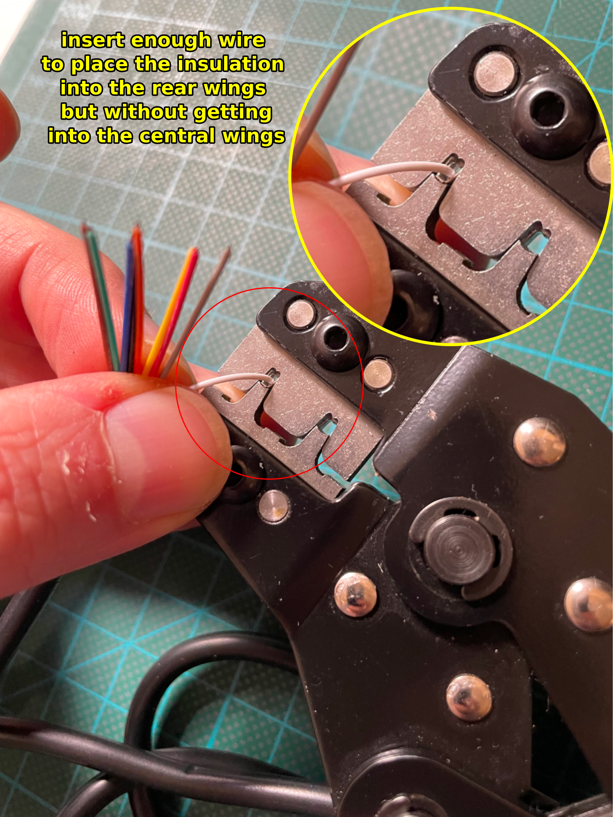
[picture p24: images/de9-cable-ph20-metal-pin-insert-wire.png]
[](images/de9-cable-ph20-metal-pin-prepare.png) [](images/de9-cable-ph20-metal-pin-clearance.png) [](images/de9-cable-ph20-metal-pin-insert-wire.png)

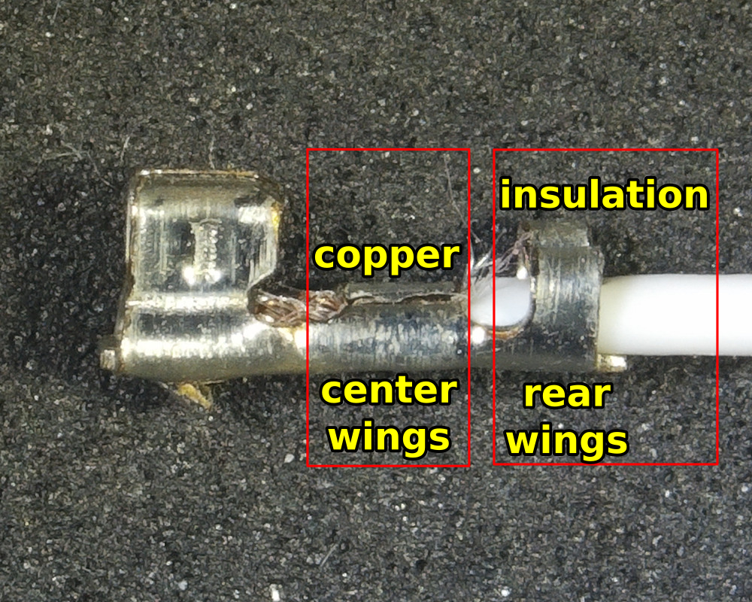
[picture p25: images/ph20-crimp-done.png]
[](images/ph20-crimp-done.png)

5. Verify with a continuity tester or digital multimeter that each wire makes a proper connection to its associated DE9 pin.

   TBC

6. Insert the continuity-verified crimped PH2.0 metal pins into the PH2.0 plastic housing.

   Looking at the plastic housing from the side where the tiny flaps are visible, and going from left to right, the order of the wires is:

   `UP, DOWN, LEFT, RIGHT, +5V, TRG-A, TRG-B, OUT, GND`

   TBC

7. At this point you can secure the cable gland using a tiny drop of glue, so that the cable gland can't move any longer.

   TBC

# Putting it all together into the acrylic enclosure

## Bill Of Materials

| **ref** | **component** | **req_pcs** | **item_description** | **item_option** | **pcs_per_item** | **req_items** | **link** |
| --- | --- | --- | --- | --- | --- | --- | --- |
| \- | M3 flat head torx screw 10mm | 8 | 10/ 20/ 50pcs Black Zinc-Plated 304 Stainless Steel M2 M2.5 M3 M4 M5 M6 CM Torx Six-Lobe Ultra Thin Flat Wafer Head Screw Bolt  | Size: M3x10mm (50pcs), Color: Black Stainles Steel | 50 | 1 | [aliexpress](https://www.aliexpress.com/item/1005004348590627.html) |
| \- | M3 nylon hex nut | 4 | 10-50pcs DIN934 M2 M2.5 M3 M4 M5 M6 PA66 White or Black Nylon Hex Nut Hexagon Plastic Nuts Metric Thread Suit For Screws Bolts | Size: M3 50pcs, Color: Black | 50 | 1 | [https://www.aliexpress.com/item/32808424957.html](https://www.aliexpress.com/item/32808424957.html) |
| \- | M3 nylon female to female 12mm hex spacer | 4 | 20/ 50Pcs M2 M2.5 M3 M4 M5 Black/ White Nylon Hex Female to Female Standoff Nylon Plastic Hexagon Thread PCB Motherboard Spacer | Size: M3 (20pcs), Length: 12mm, Color: Black | 20 | 1 | [aliexpress](https://es.aliexpress.com/item/1005004311987482.html) |
| \- | DINA4 acrylic 3mm sheet | 1 | DINA4 acrylic sheet 3mm tobacco | | 2  | 1 | |
| | laser cut service | 1 | | | 2  | 1 | |

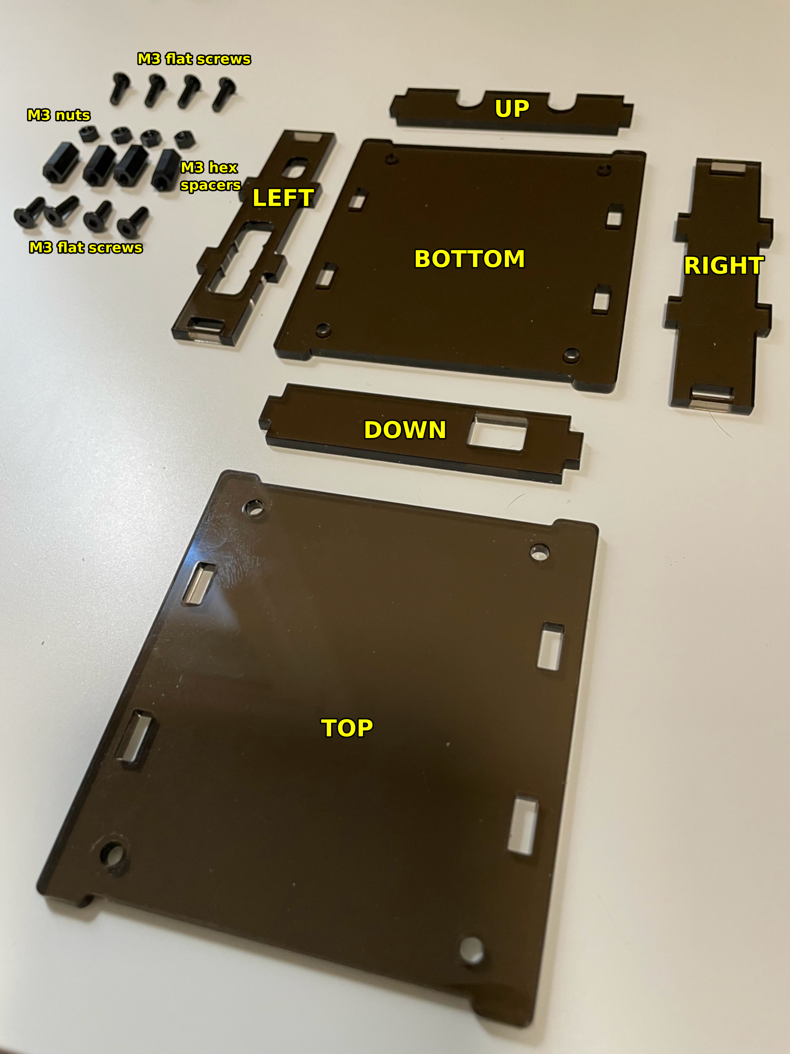
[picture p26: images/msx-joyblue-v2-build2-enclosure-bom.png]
[](images/msx-joyblue-v2-build2-enclosure-bom.png)

## Tools

I used the following tools to put together the acrylic case:

* torx screwdriver (8x60)

## Enclosure assembly instructions

1. Start by inserting four screws into the bottom enclosure panel and secure them with four nuts.

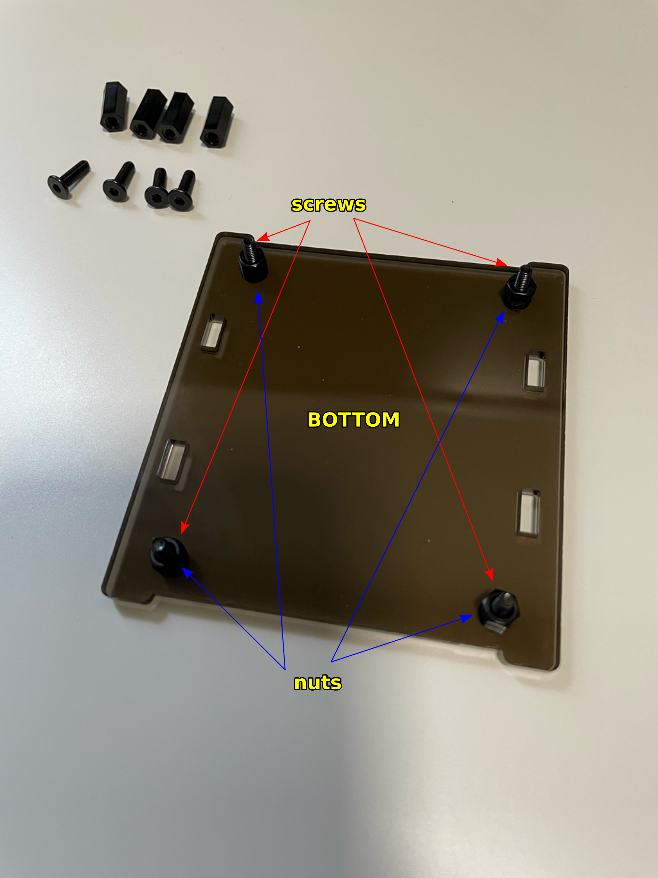
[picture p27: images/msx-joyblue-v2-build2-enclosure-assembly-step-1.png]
[](images/msx-joyblue-v2-build2-enclosure-assembly-step-1.png)

2. Slide the assembled PCB board into the screws, so that it sits on top of the nuts.

[](images/msx-joyblue-v2-build2-enclosure-assembly-step-2.png)

3. Screw the 12mm hex spacers to the screws to hold the PCB board to the enclosure.

[](images/msx-joyblue-v2-build2-enclosure-assembly-step-3.png)

4. Attach the enclosure side panels.

   Note that the UP, LEFT and DOWN panels need to be attached in a specific orientation, aligning the panel holes to the accessible board elements.

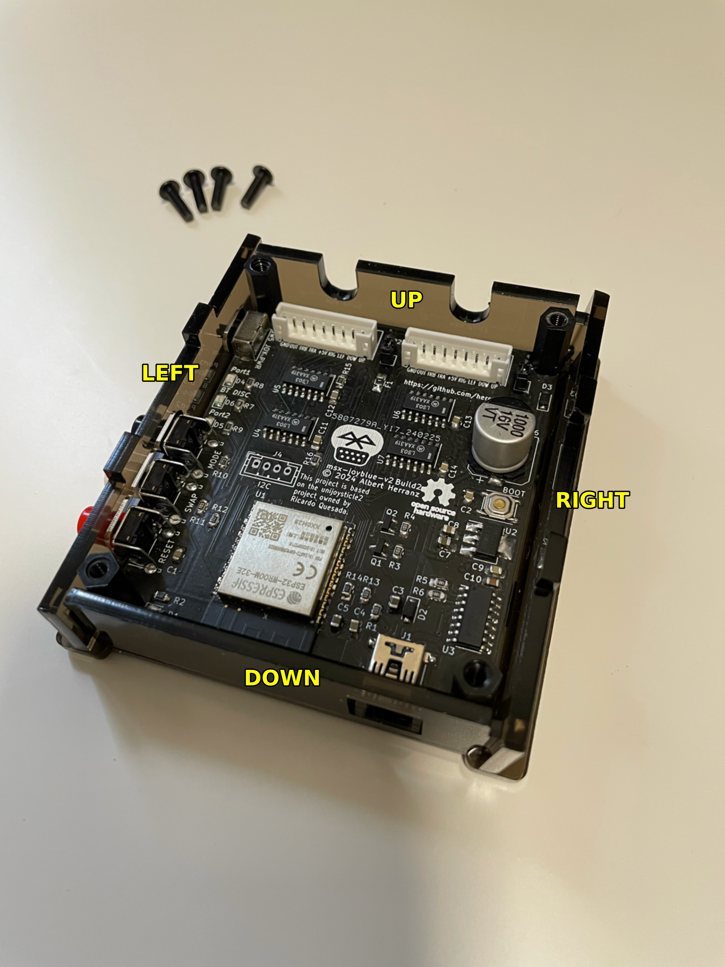
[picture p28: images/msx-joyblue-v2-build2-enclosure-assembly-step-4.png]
[](images/msx-joyblue-v2-build2-enclosure-assembly-step-4.png)

5. Install the DE9 cables.

   Connect first the PH2.0 connectors, then insert the cable glands into the enclosure UP panel holes.

   You need to put the cable gland with the part with the excess rubber removed facing up so that the enclosure can be easily closed.

[](images/msx-joyblue-v2-build2-enclosure-assembly-step-5.png)

6. Finally, attach the TOP enclosure panel.

   Secure the TOP panel using the remaining four screws.

[](images/msx-joyblue-v2-build2-enclosure-assembly-step-final.png)

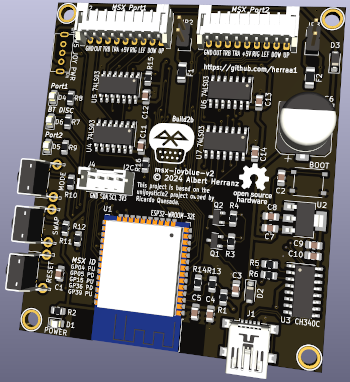
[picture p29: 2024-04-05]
images/msx-joyblue-v2-build2b-front-render-350w.png

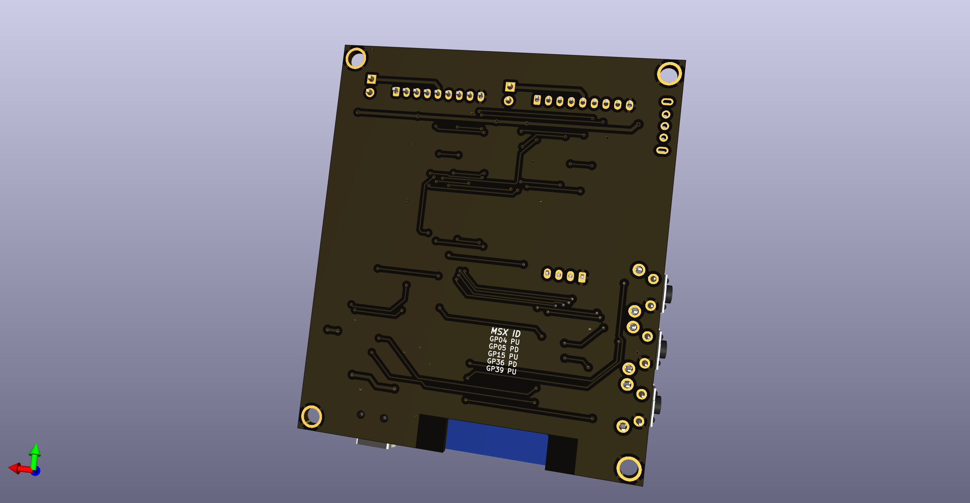
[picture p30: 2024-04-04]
images/msx-joyblue-v2-build2-rear-render.png

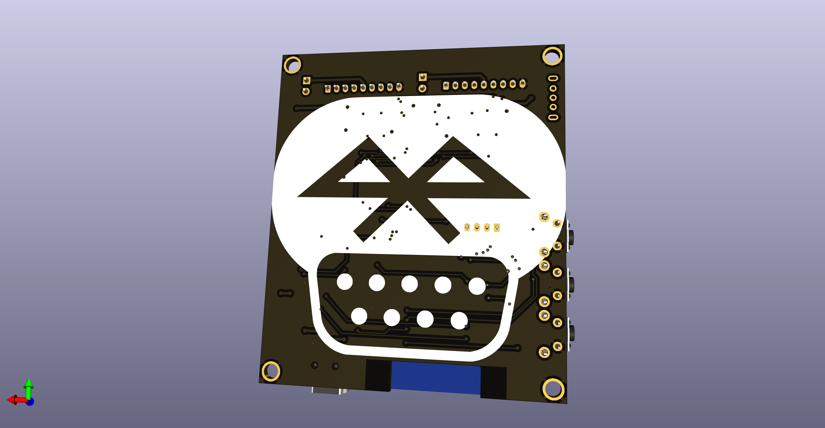
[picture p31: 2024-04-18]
images/msx-joyblue-v2-build2c-rear-render.png

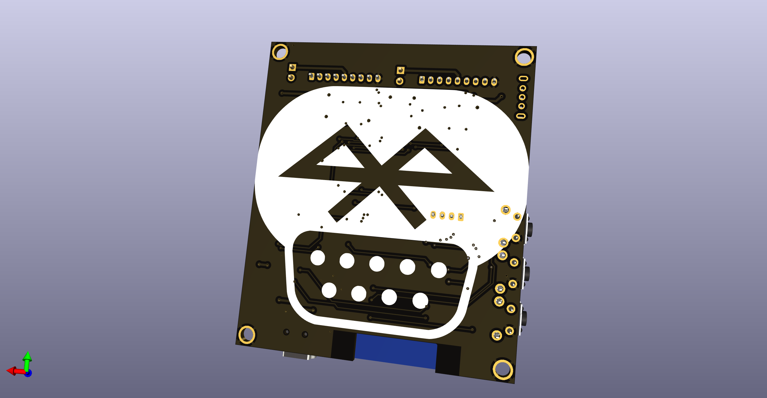
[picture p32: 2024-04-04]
images/msx-joyblue-v2-build2b-rear-render.png

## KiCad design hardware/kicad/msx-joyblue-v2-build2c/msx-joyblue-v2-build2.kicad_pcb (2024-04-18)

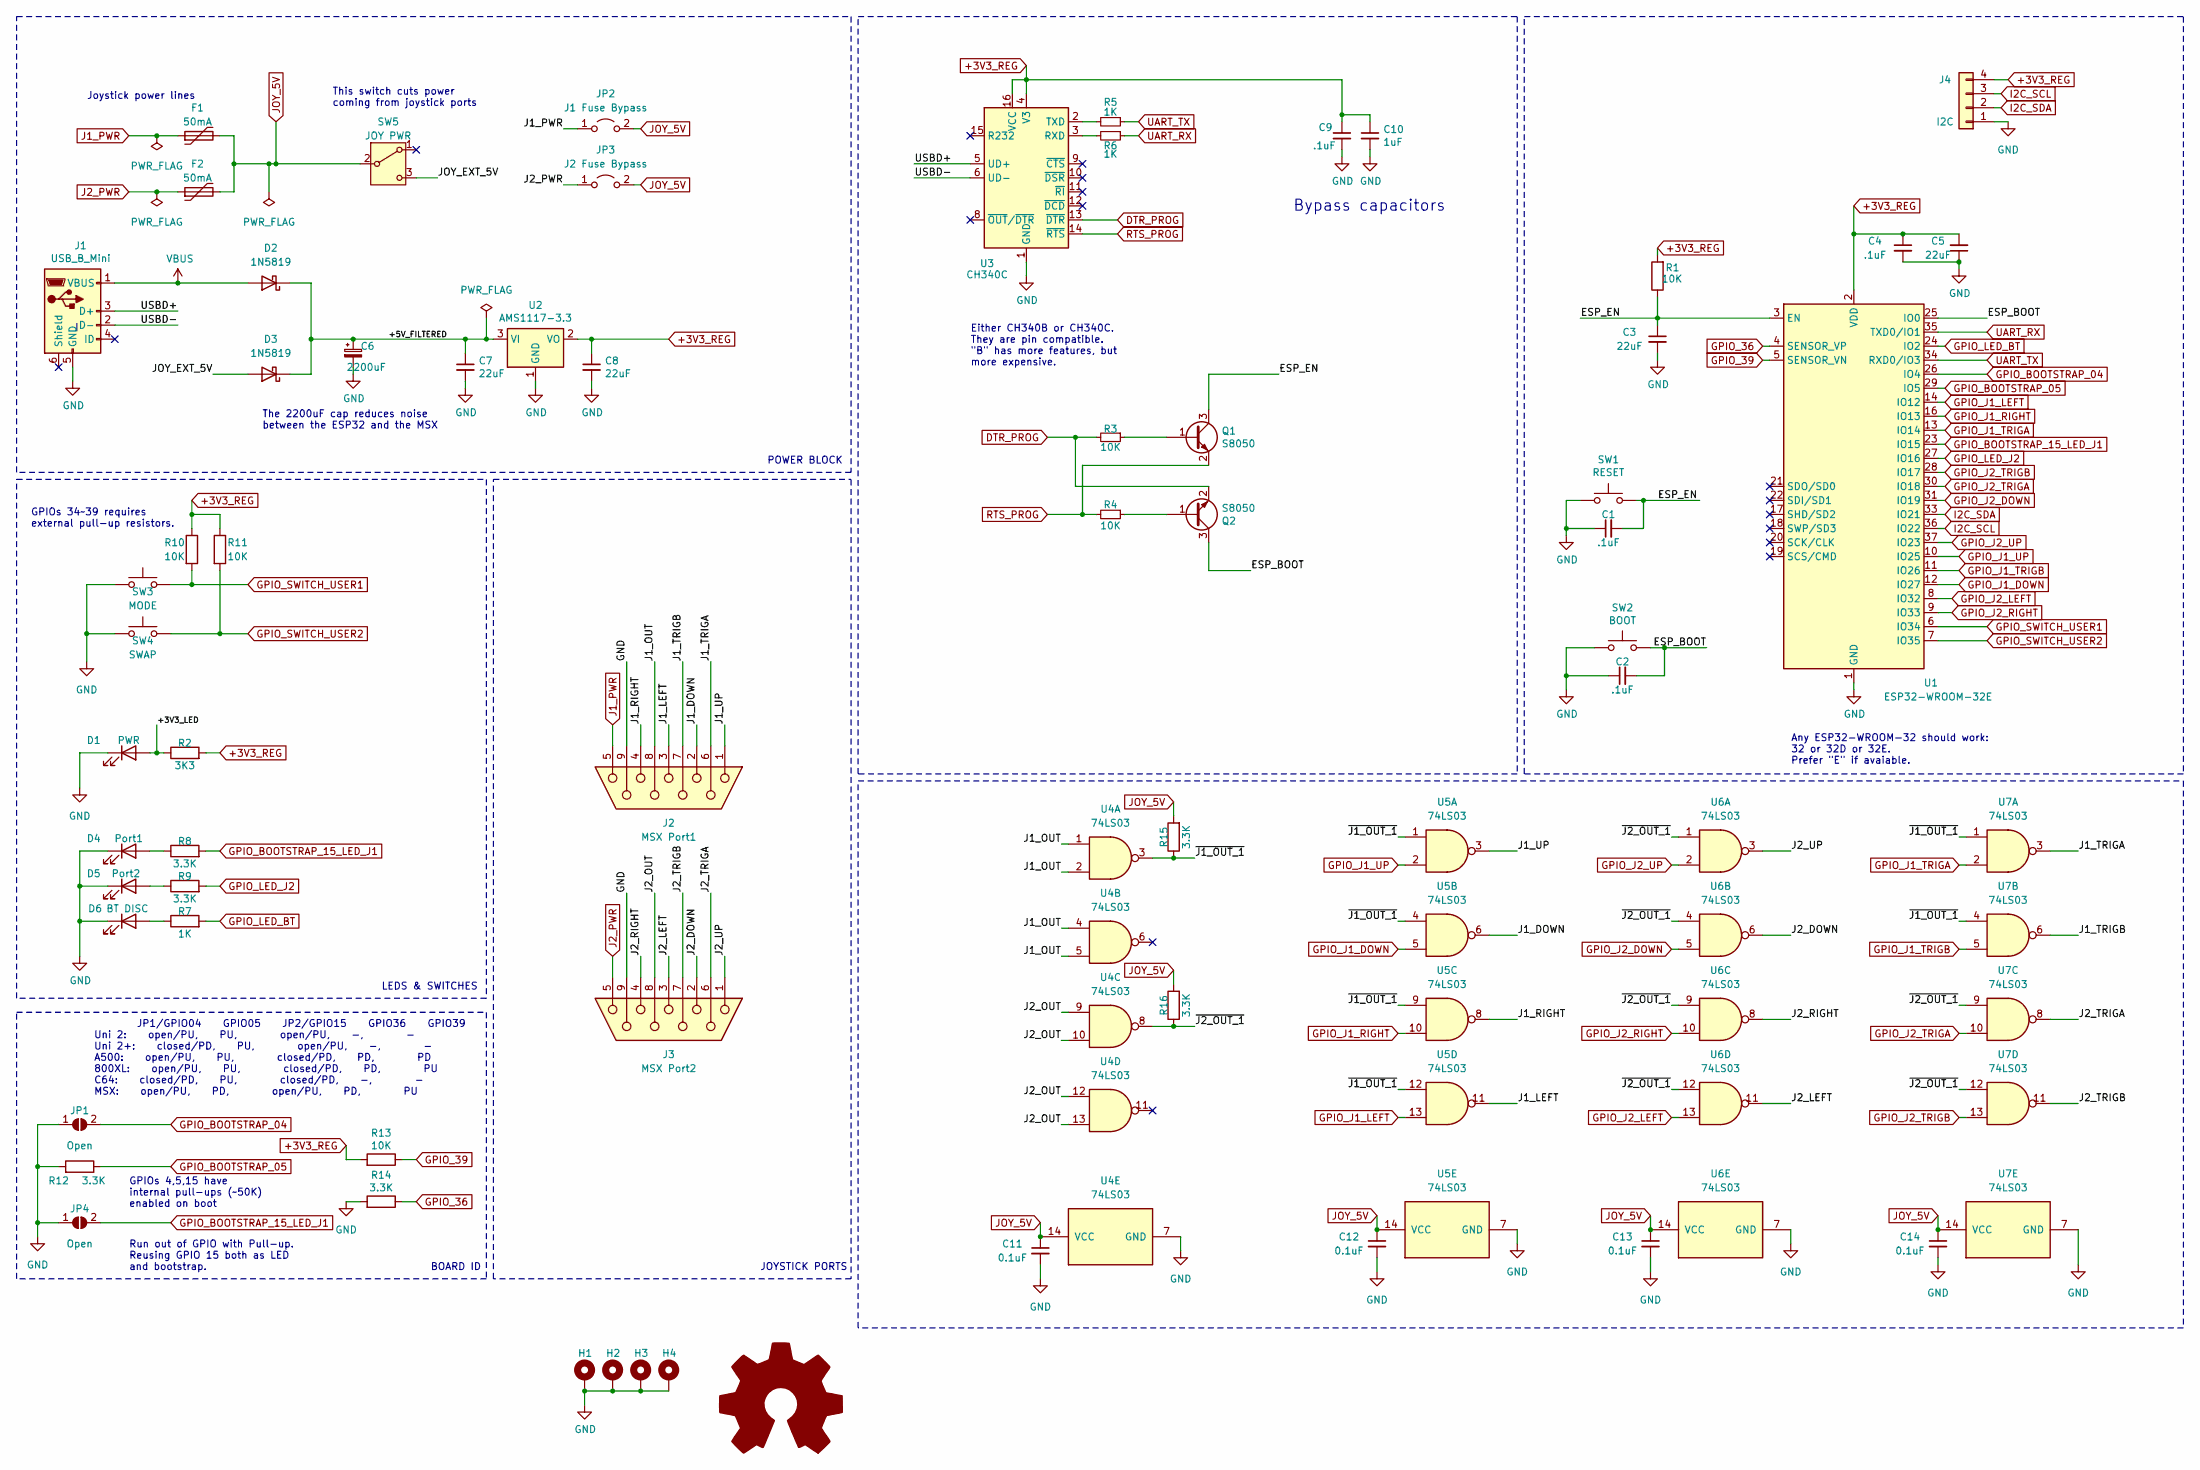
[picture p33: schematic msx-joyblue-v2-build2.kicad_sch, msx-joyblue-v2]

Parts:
C1, C2, C4, C9: .1uF; C_0805_2012Metric_Pad1.18x1.45mm_HandSolder
C3, C5, C7, C8: 22uF; C_0805_2012Metric_Pad1.18x1.45mm_HandSolder
C6: 2200uF; CP_Elec_10x10.5
C10: 1uF; C_0805_2012Metric_Pad1.18x1.45mm_HandSolder
C11, C12, C13, C14: 0.1uF; C_0805_2012Metric_Pad1.18x1.45mm_HandSolder
D1: PWR; LED_0805_2012Metric_Pad1.15x1.40mm_HandSolder
D2, D3: 1N5819; D_SOD-123
D4: Port1; LED_0805_2012Metric_Pad1.15x1.40mm_HandSolder
D5: Port2; LED_0805_2012Metric_Pad1.15x1.40mm_HandSolder
D6: BT DISC; LED_0805_2012Metric_Pad1.15x1.40mm_HandSolder
F1, F2: 50mA; Fuse_1206_3216Metric_Pad1.42x1.75mm_HandSolder
H1, H2, H3, H4: MountingHole_Pad; Hole_3mm
J1: USB_B_Mini; USB_Mini-B_Lumberg_2486_01_Horizontal
J2: MSX Port1; JST_PH_S9B-PH-K_1x09_P2.00mm_Horizontal
J3: MSX Port2; JST_PH_S9B-PH-K_1x09_P2.00mm_Horizontal
J4: I2C; JST_PH_B4B-PH-K_1x04_P2.00mm_Vertical
JP1, JP4: Open; SolderJumper-2_P1.3mm_Open_RoundedPad1.0x1.5mm
JP2: J1 Fuse Bypass; PinHeader_1x02_P2.54mm_Vertical
JP3: J2 Fuse Bypass; PinHeader_1x02_P2.54mm_Vertical
Q1, Q2: S8050; SOT-23
R1, R3, R4, R10, R11, R13: 10K; R_0805_2012Metric_Pad1.20x1.40mm_HandSolder
R2: 3K3; R_0805_2012Metric_Pad1.20x1.40mm_HandSolder
R5, R6: 1K; R_0805_2012Metric_Pad1.20x1.40mm_HandSolder
R7: 1K; R_0805_2012Metric_Pad1.20x1.40mm_HandSolder; LCSC C4310
R8, R9, R15, R16: 3.3K; R_0805_2012Metric_Pad1.20x1.40mm_HandSolder; LCSC C4310
R12, R14: 3.3K; R_0805_2012Metric_Pad1.20x1.40mm_HandSolder
SW1: RESET; SW_Tactile_SPST_Angled_PTS645Vx39-2LFS
SW2: BOOT; SW_Push_1P1T_NO_5.1x5.1mm
SW3: MODE; SW_Tactile_SPST_Angled_PTS645Vx39-2LFS
SW4: SWAP; SW_Tactile_SPST_Angled_PTS645Vx39-2LFS
SW5: JOY PWR; SW_SK-12D07G6-1P2T-6mm
SYM1: Logo_Open_Hardware_Large; OSHW-Logo_7.5x8mm_SilkScreen
U1: ESP32-WROOM-32E; ESP32-WROOM-32; LCSC C701341
U2: AMS1117-3.3; SOT-223-3_TabPin2
U3: CH340C; SOIC-16_3.9x9.9mm_P1.27mm
U4, U5, U6, U7: 74LS03; SOIC-14_3.9x8.7mm_P1.27mm

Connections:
+3V3_REG: C4.1, C5.2, C8.1, C9.1, C10.1, J4.4, R1.2, R2.2, R10.1, R11.1, R13.2, U1.2 (VDD), U2.2 (VO), U3.4 (V3), U3.16 (VCC)
/+3V3_LED: D1.2 (A), R2.1
/+5V_FILTERED: C6.1, C7.1, D2.1 (K), D3.1 (K), U2.3 (VI)
/ESP_BOOT: C2.2, Q2.3 (C), SW2.2, U1.25 (IO0)
/ESP_EN: C1.2, C3.1, Q1.3 (C), R1.1, SW1.2, U1.3 (EN)
/J1_DOWN: J2.2, U5.6
/J1_LEFT: J2.3, U5.11
/J1_OUT: J2.8, U4.1, U4.2, U4.4, U4.5
/J1_RIGHT: J2.4, U5.8
/J1_TRIGA: J2.6, U7.3
/J1_TRIGB: J2.7, U7.6
/J1_UP: J2.1, U5.3
/J2_DOWN: J3.2, U6.6
/J2_LEFT: J3.3, U6.11
/J2_OUT: J3.8, U4.9, U4.10, U4.12, U4.13
/J2_RIGHT: J3.4, U6.8
/J2_TRIGA: J3.6, U7.8
/J2_TRIGB: J3.7, U7.11
/J2_UP: J3.1, U6.3
/JOY_EXT_5V: D3.2 (A), SW5.3 (C)
/USBD+: J1.3 (D+), U3.5 (UD+)
/USBD-: J1.2 (D-), U3.6 (UD-)
/~J1_OUT_1: R15.1, U4.3, U5.1, U5.4, U5.9, U5.12, U7.1, U7.4
/~J2_OUT_1: R16.1, U4.8, U6.1, U6.4, U6.9, U6.12, U7.9, U7.12
DTR_PROG: Q2.2 (E), R3.2, U3.13 (~DTR)
GND: C1.1, C2.1, C3.2, C4.2, C5.1, C6.2, C7.2, C8.2, C9.2, C10.2, C11.2, C12.2, C13.2, C14.2, D1.1 (K), D4.1 (K), D5.1 (K), D6.1 (K), H1.1, H2.1, H3.1, H4.1, J1.5 (GND), J2.9, J3.9, J4.1, JP1.1 (A), JP4.1 (A), R12.2, R14.2, SW1.1, SW2.1, SW3.1, SW4.1, U1.1 (GND), U1.15 (GND), U1.38 (GND), U1.39 (GND), U2.1 (GND), U3.1 (GND), U4.7 (GND), U5.7 (GND), U6.7 (GND), U7.7 (GND)
GPIO_36: R14.1, U1.4 (SENSOR_VP)
GPIO_39: R13.1, U1.5 (SENSOR_VN)
GPIO_BOOTSTRAP_04: JP1.2 (B), U1.26 (IO4)
GPIO_BOOTSTRAP_05: R12.1, U1.29 (IO5)
GPIO_BOOTSTRAP_15_LED_J1: JP4.2 (B), R8.2, U1.23 (IO15)
GPIO_J1_DOWN: U1.12 (IO27), U5.5
GPIO_J1_LEFT: U1.14 (IO12), U5.13
GPIO_J1_RIGHT: U1.16 (IO13), U5.10
GPIO_J1_TRIGA: U1.13 (IO14), U7.2
GPIO_J1_TRIGB: U1.11 (IO26), U7.5
GPIO_J1_UP: U1.10 (IO25), U5.2
GPIO_J2_DOWN: U1.31 (IO19), U6.5
GPIO_J2_LEFT: U1.8 (IO32), U6.13
GPIO_J2_RIGHT: U1.9 (IO33), U6.10
GPIO_J2_TRIGA: U1.30 (IO18), U7.10
GPIO_J2_TRIGB: U1.28 (IO17), U7.13
GPIO_J2_UP: U1.37 (IO23), U6.2
GPIO_LED_BT: R7.2, U1.24 (IO2)
GPIO_LED_J2: R9.2, U1.27 (IO16)
GPIO_SWITCH_USER1: R10.2, SW3.2, U1.6 (IO34)
GPIO_SWITCH_USER2: R11.2, SW4.2, U1.7 (IO35)
I2C_SCL: J4.3, U1.36 (IO22)
I2C_SDA: J4.2, U1.33 (IO21)
J1_PWR: F1.1, J2.5, JP2.1 (A)
J2_PWR: F2.1, J3.5, JP3.1 (A)
JOY_5V: C11.1, C12.1, C13.1, C14.1, F1.2, F2.2, JP2.2 (B), JP3.2 (B), R15.2, R16.2, SW5.2 (B), U4.14 (VCC), U5.14 (VCC), U6.14 (VCC), U7.14 (VCC)
unnamed: D4.2 (A), R8.1
unnamed: D5.2 (A), R9.1
unnamed: D6.2 (A), R7.1
unnamed: Q1.1 (B), R3.1
unnamed: Q2.1 (B), R4.1
unnamed: R6.2, U3.3 (RXD)
unnamed: R5.2, U3.2 (TXD)
RTS_PROG: Q1.2 (E), R4.2, U3.14 (~RTS)
UART_RX: R6.1, U1.35 (TXD0/IO1)
UART_TX: R5.1, U1.34 (RXD0/IO3)
VBUS: D2.2 (A), J1.1 (VBUS)

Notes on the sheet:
JP1/GPIO04 GPIO05 JP2/GPIO15 GPIO36 GPIO39 Uni 2: open/PU, PU, open/PU, -, - Uni 2+: closed/PD, PU, open/PU, -, - A500: open/PU, PU, closed/PD, PD, PD 800XL: open/PU, PU, closed/PD, PD, PU C64: closed/PD, PU, closed/PD, -, - MSX: open/PU, PD, open/PU, PD, PU
This switch cuts power coming from joystick ports
GPIOs 4,5,15 have internal pull-ups (~50K) enabled on boot
BOARD ID
Joystick power lines
GPIOs 34~39 requires external pull-up resistors.
POWER BLOCK
JOYSTICK PORTS
Bypass capacitors
Run out of GPIO with Pull-up. Reusing GPIO 15 both as LED and bootstrap.
LEDS & SWITCHES
Either CH340B or CH340C. They are pin compatible. "B" has more features, but more expensive.
Any ESP32-WROOM-32 should work: 32 or 32D or 32E. Prefer "E" if avaiable.
The 2200uF cap reduces noise between the ESP32 and the MSX

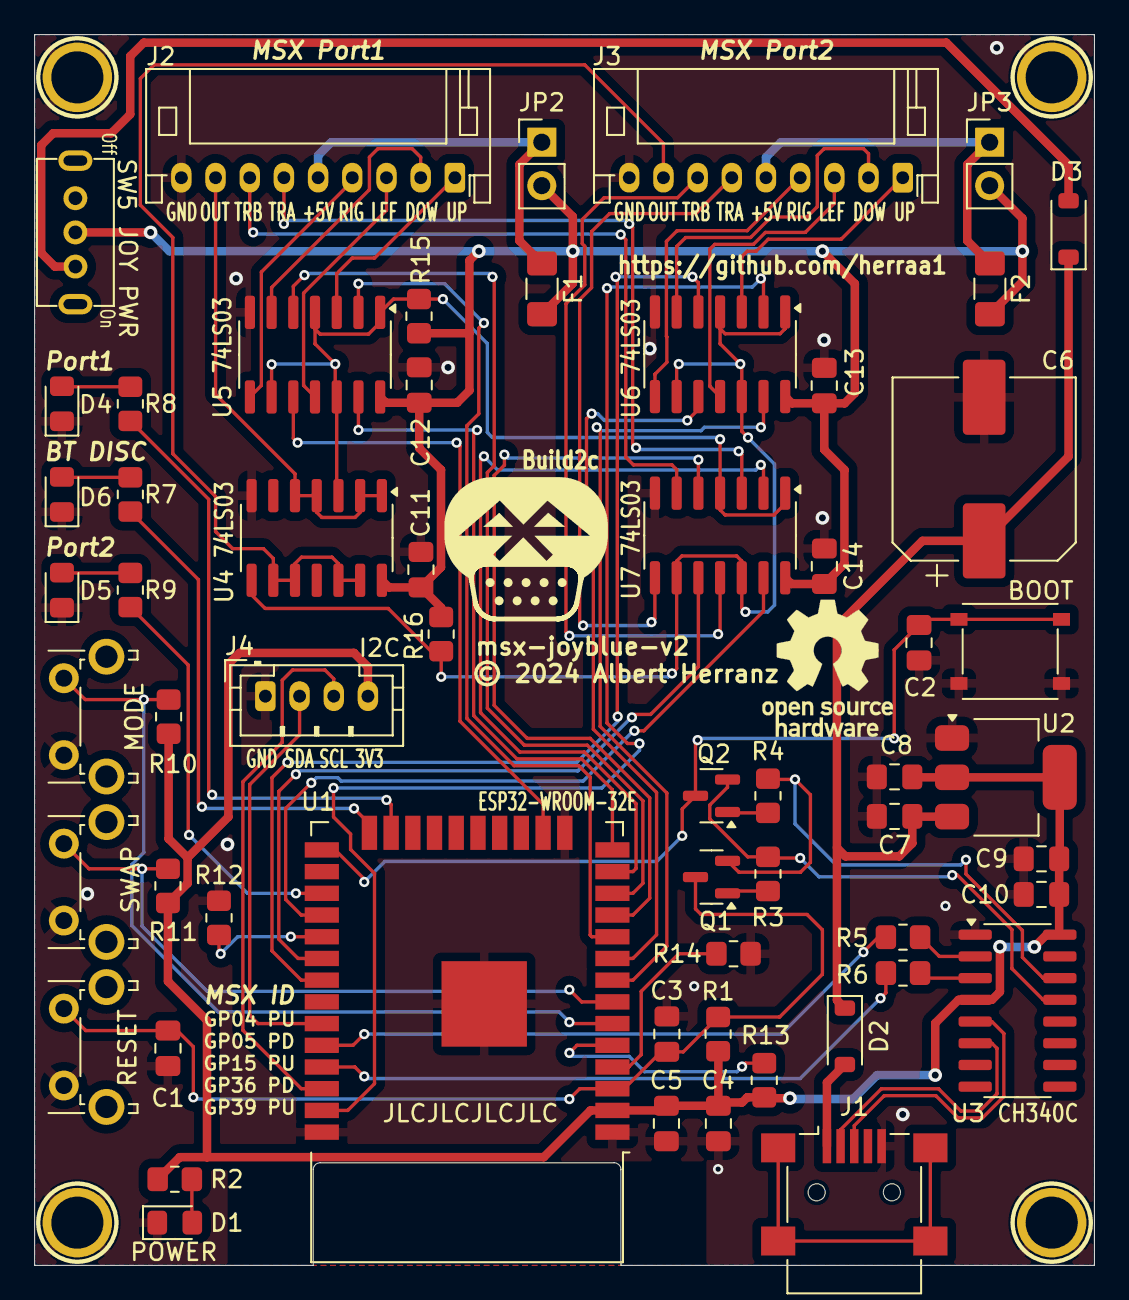
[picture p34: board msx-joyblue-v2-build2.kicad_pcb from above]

Board: 2 copper layers, 62.0 x 72.0 mm, 63 parts (0 on the bottom side), 62 nets.

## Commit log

2024-04-04 Initial commit.
    [msx-joyblue-v2-build2.kicad_pcb, msx-joyblue-v2-build2.kicad_sch]
2024-04-04 Fix BoM links
2024-04-04 Fix (maybe) BoM links
2024-04-06 enclosure: rework design, fix strain relief holes
    [msx-joyblue-v2-case-ready-to-lasercut.dxf]
2024-04-18 add Build2c
    [msx-joyblue-v2-build2.kicad_pcb, msx-joyblue-v2-build2.kicad_sch]
2024-04-18 enclosure: rework
    [msx-joyblue-v2-case-ready-to-lasercut.dxf]
2024-04-27 enclosure and build2c updates
    [msx-joyblue-v2-case-acrylic-3mm-ready-to-lasercut.dxf, msx-joyblue-v2-case-ready-to-lasercut.dxf]
2024-04-27 readme: acrylic enclosure is ready to use
2024-05-06 readme: leds, buttons and compatibility tests updates
2024-05-11 build: add test instructions for ESP32
2024-05-19 build: add images for buiding cables
2025-09-17 readme: add reference to new BoM at PCBWay

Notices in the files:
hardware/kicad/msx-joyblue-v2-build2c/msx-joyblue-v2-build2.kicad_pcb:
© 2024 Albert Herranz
